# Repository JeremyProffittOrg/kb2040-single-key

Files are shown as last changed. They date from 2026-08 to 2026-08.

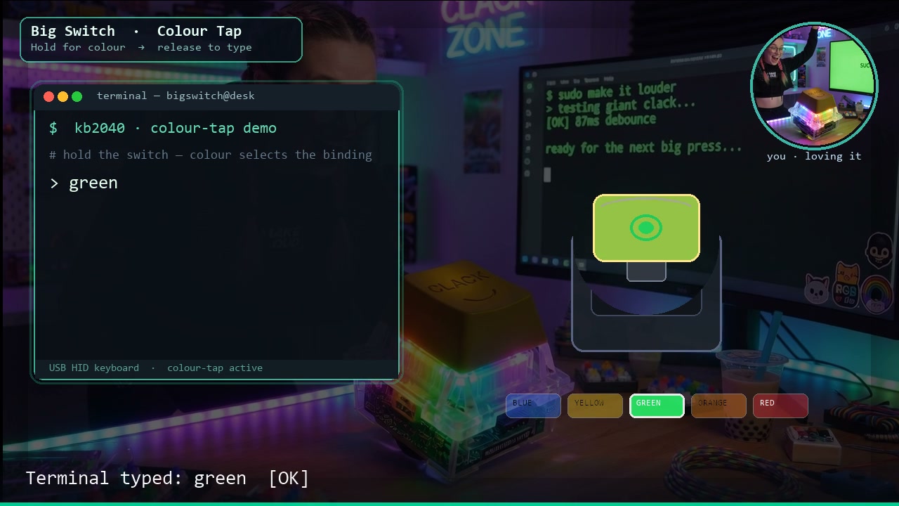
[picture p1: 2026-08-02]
docs/images/demo-hero.jpg

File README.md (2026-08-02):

# kb2040-single-key

One key. Many actions. The colour tells you which one.

https://github.com/user-attachments/assets/82b076d7-507e-4828-8a83-83113fe58dd0

An [Adafruit KB2040](https://www.adafruit.com/product/5302) with a single **Kailh Big Switch**
and a [NeoPixel Jewel](https://www.adafruit.com/product/2859) under (or beside) it, which
enumerates as a USB keyboard **and** a second USB serial port used only for configuration.
Configuration lives on the board, survives a power cycle, and is edited with a
cross-platform CLI.

Verified on an Adafruit KB2040 running **CircuitPython 10.2.1**. The default profile expects
an eight-pixel chain; with a 7-LED Jewel set `ext_count` to `7` (see
[Build guide](#build-guide)). A full command reference is in
[`docs/kb2040ctl-manual.pdf`](docs/kb2040ctl-manual.pdf).

| Core parts | Link |
|---|---|
| Controller | [Adafruit KB2040 — RP2040 Kee Boar Driver](https://www.adafruit.com/product/5302) |
| Lighting | [NeoPixel Jewel — 7 × 5050 RGB(W)](https://www.adafruit.com/product/2859) (any Jewel variant works) |
| Switch | [Kailh Big Switches](https://www.adafruit.com/category/571) (clicky blue / tactile orange / linear yellow) |
| Case | [`BigSwitchCase.stl`](BigSwitchCase.stl) · [`BigSwitchCase.scad`](BigSwitchCase.scad) |

---

## Bill of materials

### Required electronics

| Qty | Part | Adafruit / source | Notes |
|---:|---|---|---|
| 1 | **Adafruit KB2040** | [product 5302](https://www.adafruit.com/product/5302) · ~$8.95 | RP2040, Pro Micro footprint, USB-C, onboard NeoPixel |
| 1 | **NeoPixel Jewel** (7 LEDs) | [product 2859](https://www.adafruit.com/product/2859) RGBW Natural White, or [2226](https://www.adafruit.com/product/2226) RGB | ~23 mm diameter. Firmware talks plain WS2812 data on `D10` |
| 1 | **Kailh Big Switch** + keycap | [Big Switches category](https://www.adafruit.com/category/571) · ~$19.95 | [5307](https://www.adafruit.com/product/5307) clicky pale blue · [5306](https://www.adafruit.com/product/5306) tactile burnt orange · [5305](https://www.adafruit.com/product/5305) linear dark yellow |
| 1 | USB-C cable | any data-capable cable | Power + HID + config serial |

### Printed / mechanical

| Qty | Part | File | Notes |
|---:|---|---|---|
| 1 | **Big Switch case (base)** | [`BigSwitchCase.stl`](BigSwitchCase.stl) | Outer envelope ≈ **84 × 84 × 65 mm**. Print with the flat base on the bed |
| — | OpenSCAD source | [`BigSwitchCase.scad`](BigSwitchCase.scad) | Mesh polyhedron of the same solid (for inspection / remix) |

Optional: a thin diffuser disk or clear plate under the keycap if you want the Jewel to glow through the switch housing; the stock Kailh Big keycap is opaque, so many builds mount the Jewel in the base looking upward around the switch, or light the desk from under a translucent base.

### Consumables / tools

| Item | Why |
|---|---|
| Hookup wire (or short pre-crimped jumpers) | Switch to `D4`/`GND`; Jewel `DIN`/`5V`/`GND` to `D10`/`RAW`/`GND` |
| Soldering iron + solder | Headers (if used), switch legs, Jewel pads |
| Flux / flush cutters | Clean joints |
| Small flat screwdriver | **Required to release the Big Switch from the case** — see diagram below |
| 3D printer + filament | PLA or PETG for the case |

Rough electronics total (one of each, USD list prices): **≈ $35–40** before shipping, cable, and filament.

---

## Case: tab-release openings

The Big Switch snaps into the printed base. It is **not** meant to be pried out by the keycap.
On opposite sides of the case there are **square openings**. Through each opening you can reach
a plastic **retention tab** on the switch body.

1. Insert a **small flat screwdriver** into the square opening on one side.
2. Push **inward** on the tab (toward the centre of the switch).
3. Repeat on the **opposite** opening.
4. Lift the switch **straight up** out of the base.

BigSwitchCase tab-release openings — top and side views

> Do not force the housing. If a tab is still caught, go back to that side and push again
> while lifting gently. Forcing the keycap can crack the stem or the printed wall.

---

## Build guide

### 1. Print the case

- Slice [`BigSwitchCase.stl`](BigSwitchCase.stl) (or render [`BigSwitchCase.scad`](BigSwitchCase.scad)).
- Orientation: **flat base on the bed**, openings vertical.
- Suggested start: 0.2 mm layers, 15–20% infill, 3 walls. Supports usually unnecessary if
  printed base-down; enable them only if your slicer flags the openings.
- After printing, clean the two **square side openings** with a knife or small file so a
  screwdriver blade enters cleanly.

### 2. Fit-check the switch (no solder yet)

1. Align the Kailh Big Switch with the cavity (legs/orientation as your wiring prefers —
   note which side the two electrical pins face).
2. Press the switch straight down until both tabs click.
3. Practice the **tab release** with the screwdriver through both square openings so you are
   comfortable removing it before anything is wired.

### 3. Wire the electronics

Follow the [Wiring](#wiring) table. Short summary for this build:

| Connection | From | To |
|---|---|---|
| Switch contact A | Big Switch pin 1 | KB2040 **`D4`** |
| Switch contact B | Big Switch pin 2 | KB2040 **`GND`** |
| LED data | Jewel **`DIN`** (or `In`) | KB2040 **`D10`** |
| LED power | Jewel **`+` / 5V** | KB2040 **`RAW`** (USB 5 V) |
| LED ground | Jewel **`–` / GND** | KB2040 **`GND`** |

```
   KB2040                         NeoPixel Jewel (7)
   ------                         ------------------
   D10  ------------------------>  DIN
   RAW  ------------------------>  +5V
   GND  ------------------------>  GND

   D4   ---[ Kailh Big Switch ]--- GND
```

**Tips**

- Solder the Jewel first if it will sit under the switch — access is harder later.
- Keep the data wire short. If colours glitch, see the [power / 3.3 V data notes](#wiring).
- The onboard NeoPixel needs no wiring; it mirrors status on its own.
- Leave USB-C and the BOOT/RESET buttons accessible (side cutout or open base).

### 4. Install into the case

1. Seat the Jewel (and any diffuser) in the base.
2. Route wires so they do not block a tab or the square openings.
3. Snap the Big Switch in until both tabs catch.
4. Mount or tape the KB2040 in the base (or in a side pocket if you remix the case). USB-C
   should face an opening so the cable does not stress the board.

### 5. Flash firmware and set LED count

1. Install CircuitPython and flash this firmware — [Getting started](#getting-started).
2. For a **7-LED Jewel**, set the external chain length (per active profile):

```bash
kb2040ctl set profiles.0.ext_count 7
kb2040ctl set profiles.1.ext_count 7   # if you use profile 1 as well
```

3. Unplug/replug. On boot you should see the **rainbow sweep** on the onboard pixel and all
   seven Jewel LEDs. Then try a tap and a colour-hold ([The colour tap](#the-colour-tap)).

### 6. Removing the switch later

Use the square openings and a small screwdriver as in
[Case: tab-release openings](#case-tab-release-openings). Pull the switch only after **both**
tabs are free.

---

## The colour tap

A single key can only do one thing — unless you use time and colour as the extra input.

- **Tap** it (press and release quickly) and it fires the profile's **tap** binding.
- **Tap and hold** and, once past the tap window, the LEDs start cycling through colours,
  one per second. Each colour is a **slot**. Let go while a colour is showing and *that*
  slot fires.

The LED is the entire user interface: hold, watch for the colour you want, release.

```
press                                                                 
  |<-- tap window -->|<-- slot 0 --->|<-- slot 1 --->|<-- slot 2 --->|
  |     250 ms       |    1000 ms    |    1000 ms    |    1000 ms    |
  |     (white)      |     (red)     |   (orange)    |   (yellow)    |
  0                 250            1250            2250            3250 ms

  release here...    ...or here      ...or here      ...or here
  -> tap binding     -> slot 0       -> slot 1       -> slot 2
```

`tap_max_ms` (default 250) and `dwell_ms` (default 1000) are per-profile settings.

### Past the last colour

What happens when you keep holding is the per-profile `overflow` setting:

| `overflow` | behaviour |
|---|---|
| `wrap` | back to the first colour, cycling forever. Overshoot is recoverable — keep holding. |
| `wrap_cancel` | as `wrap`, but with one **dark** slot per rotation. Release while the LEDs are off and **nothing fires**. This is the escape hatch. |
| `clamp` | stay on the last colour indefinitely. Forgiving of long holds, but you can never reach an earlier slot without releasing and starting again. |

### What a binding can do

Every binding — the tap and each colour slot — is a **sequence** of steps, run in order:

| step | example | effect |
|---|---|---|
| key | `{ "key": "M", "mods": ["CTRL", "SHIFT"] }` | press with modifiers, then release |
| text | `{ "text": "On my way." }` | type the string |
| media | `{ "consumer": "PLAY_PAUSE" }` | a Consumer Control usage (play/pause, volume, …) |
| delay | `{ "delay_ms": 200 }` | wait before the next step |

So one slot can select-all-and-copy, another can type a canned reply and press Enter, and
another can mute your microphone.

### Profiles

The board stores several complete configurations and one is active at a time. Switch with
`kb2040ctl profile use 1`. Profiles are uploaded and downloaded as JSON, so you can keep as
many on disk as you like.

## Out of the box

The factory configuration has two profiles. Profile 0, `colors`, is active and is
deliberately self-describing:

| Gesture | Colour | Action |
|---|---|---|
| tap | white | **Print Screen** |
| hold → release on slot 0 | red | types `Red` |
| hold → release on slot 1 | orange | types `Orange` |
| hold → release on slot 2 | yellow | types `Yellow` |
| hold → release on slot 3 | green | types `Green` |
| hold → release on slot 4 | cyan | types `Cyan` |
| hold → release on slot 5 | blue | types `Blue` |
| hold → release on slot 6 | violet | types `Violet` |
| hold → release on slot 7 | magenta | types `Magenta` |

One slot per LED in the default eight-pixel chain, in the same order the startup rainbow
sweeps them. Because each slot types the name of the colour it is showing, the gesture
teaches itself: hold, watch the strip, release, and the word that appears tells you whether
you let go when you meant to.

Profile 1, `media`, is play/pause on tap with mute, volume and track controls on the colour
slots — switch to it with `kb2040ctl profile use 1`.

---

## Wiring

Reference hardware for this repo is the **KB2040 + Kailh Big Switch + NeoPixel Jewel**
build described in the [Bill of materials](#bill-of-materials) and
[Build guide](#build-guide). Any momentary switch to ground and any WS2812-compatible chain
on `D10` will work the same electrically.

| Function | Pin | Notes |
|---|---|---|
| Key switch (Kailh Big Switch) | `D4` (GP4) | other leg to `GND`. Internal pull-up, active low — no resistor needed. |
| Onboard NeoPixel | `NEOPIXEL` (GP17) | already on the board, nothing to wire |
| External WS2812 data (Jewel `DIN`) | `D10` (GP10) | first pixel's `DIN` |
| External WS2812 power | `RAW` (5 V) and `GND` | see the power note below |

```
   KB2040                      WS2812 chain / NeoPixel Jewel
   ------                      -----------------------------
   D10  --------------------->  DIN
   RAW  --------------------->  5V
   GND  --------------------->  GND
                                 |
   D4   ---[ key switch ]--- GND |
```

**Power.** A WS2812 draws up to ~60 mA at full white. `RAW` comes straight from USB VBUS, so
the practical ceiling is what the host port will give — budget roughly 8–10 pixels before
adding a separate 5 V supply (tie its ground to the board's). A 7-LED Jewel is well inside
that. The default `brightness` of 64 keeps a chain of 7–8 to about a fifth of full-white draw.

**3.3 V data into a 5 V part.** The RP2040's output is 3.3 V and WS2812 datasheets ask for
0.7 × VDD. It usually works at short distances, and reliably if you power the chain at
4.5 V or use WS2812B-family parts. If the first pixel flickers or shows wrong colours, that
is the reason — add a level shifter or drop the strip supply.

To use different pins, change `KEY_PIN` and `EXT_PIN` at the top of `src/code.py`.

---

## Getting started

### 1. Put CircuitPython on the board

Skip this if the board already shows up as a `CIRCUITPY` drive.

Get it into the UF2 bootloader so an `RPI-RP2` drive appears:

- **double-tap RESET** quickly, or
- **hold BOOT while tapping RESET** (or while plugging the USB cable in), or
- if the board is running an **Arduino** sketch, the double-tap often does nothing — use the
  standard Arduino *1200-baud touch* instead: open its serial port at 1200 baud and close
  it, and it reboots into the bootloader.

Then copy the [KB2040 CircuitPython build](https://circuitpython.org/board/adafruit_kb2040/)
onto `RPI-RP2`. The board reboots as `CIRCUITPY`.

> **Get the board-specific build.** Nothing on the bootloader drive identifies the board —
> `INFO_UF2.TXT` always reads `Model: Raspberry Pi RP2`, because the bootloader lives in the
> RP2040's mask ROM and is identical on every RP2040. The `.uf2` is what defines
> `board.NEOPIXEL`, `board.D4` and `board.D10`, so the wrong one breaks exactly the pins this
> firmware uses. Once CircuitPython is on, `boot_out.txt` names the board for real.

### 2. Flash the firmware

```powershell
pip install -r requirements-dev.txt
pwsh scripts/flash.ps1          # Windows
```

```bash
pip install -r requirements-dev.txt
scripts/flash.sh                # macOS and Linux
```

Both install the CircuitPython libraries with `circup` and copy `src/` onto the drive. If the
volume is mounted somewhere unusual — common on headless Linux, which may not automount at
all — pass it explicitly: `scripts/flash.sh --drive /mnt/CIRCUITPY`.
Then **unplug and replug the board** — `boot.py` only takes effect on a hard reset, and it
is what creates the second serial port.

On every start the board runs a **rainbow sweep** across the onboard NeoPixel and the whole
external chain, then settles into the profile's idle animation. That is the self-test: if
all your pixels light and show a smooth spread of colour, the data line, the chain length
and the power are all good. It runs regardless of the profile's `idle_mode` and stays
visible even at `brightness: 0`, because it is the only diagnostic the board has before
anything can talk to it.

### 3. Build the CLI

```bash
go build -o kb2040ctl ./cli/cmd/kb2040ctl
```

Or download a prebuilt binary from the releases page — Windows, macOS and Linux, amd64 and
arm64, no runtime to install.

Two per-platform notes, both covered in the [manual](docs/kb2040ctl-manual.pdf): macOS
quarantines a downloaded binary, so clear it with
`xattr -d com.apple.quarantine ./kb2040ctl`; and on Linux `/dev/ttyACM*` belongs to the
`dialout` group, so `sudo usermod -aG dialout "$USER"` (then log out and in) avoids
*permission denied*.

### 4. Check it

```console
$ kb2040ctl ports
   COM27        USB Serial Device (COM27)  [USB 239A:8106]
-> COM28        USB Serial Device (COM28)  [USB 239A:8106]
   COM3         Standard Serial over Bluetooth link (COM3)

$ kb2040ctl info
port       COM28
firmware   0.1.0 (format 1)
storage    204 / 4096 bytes used (3892 free)

* 0  colors           8 slots, 1000ms dwell, wrap overflow, 8 LEDs
  1  media            6 slots, 1000ms dwell, wrap_cancel overflow, 8 LEDs
```

Two ports appear because the board exposes both the REPL console and the config port
(`COM27`/`COM28` on Windows, `/dev/ttyACM0`/`/dev/ttyACM1` on Linux, `/dev/cu.usbmodem*` on
macOS). They have identical USB IDs, so `kb2040ctl` finds the right one by asking each until
one answers. Bluetooth ports are never probed — opening an idle one on Windows can block for
minutes — and on macOS only the `/dev/cu.*` names are tried, since opening a `/dev/tty.*`
twin waits forever for carrier detect.

---

## Configuring

### Edit one thing

```bash
kb2040ctl set profiles.0.dwell_ms 1500
kb2040ctl set profiles.0.slots.2.color "#00FF80"
kb2040ctl set profiles.0.slots.0.steps.0.text "Back in five."
kb2040ctl get profiles.0.overflow
```

`set` downloads the configuration, applies the edit, validates it and uploads the result —
the board is only ever written whole, so a half-applied configuration is not possible.

### Edit a file

```bash
kb2040ctl download -o mine.json     # whole device
$EDITOR mine.json
kb2040ctl validate mine.json        # check it without a board attached
kb2040ctl upload mine.json
```

Or one profile at a time:

```bash
kb2040ctl download -p 0 -o media.json
kb2040ctl upload -p 1 examples/meetings.json
```

### Tune the timing by feel

```console
$ kb2040ctl watch
Watching. Tap and hold the key; press Ctrl-C to stop.
press
slot 0 FF0000
slot 1 FF6000
slot 2 FFC000
release
fire 3
```

If you keep overshooting, raise `dwell_ms`. If a deliberate tap keeps landing on slot 0,
raise `tap_max_ms`.

---

## Command reference

| Command | What it does |
|---|---|
| `kb2040ctl ports` | list serial ports and show which one is the board |
| `kb2040ctl info` | show firmware version, storage use and the active profile |
| `kb2040ctl download [-p N] [-o FILE]` | save the device's configuration as JSON |
| `kb2040ctl upload [-p N] FILE` | send a JSON configuration to the device |
| `kb2040ctl get PATH` | print one value from the device's configuration |
| `kb2040ctl set PATH VALUE` | change one value and upload the result |
| `kb2040ctl profile list\|use N` | list profiles or switch the active one |
| `kb2040ctl test PROFILE BINDING` | fire a binding now (binding 0 is the tap) |
| `kb2040ctl watch` | print key and colour-slot events live |
| `kb2040ctl validate FILE` | check a configuration file without a device |
| `kb2040ctl defaults` | restore the factory configuration |
| `kb2040ctl keys [media]` | list the key and media names a config can use |
| `kb2040ctl version` | print this tool's version |

Every command that talks to the board takes `-port COM7` (or `/dev/ttyACM1`) to skip
autodetection. `validate`, `keys` and `version` need no board at all.

---

## Configuration format

```jsonc
{
  "format": 1,
  "active": 0,
  "profiles": [
    {
      "name": "media",          // up to 16 bytes
      "dwell_ms": 1000,         // 100..10000 - how long each colour shows
      "tap_max_ms": 250,        // 20..2000  - release under this is a tap
      "overflow": "wrap",       // wrap | wrap_cancel | clamp
      "ext_count": 8,           // 0..64 external WS2812s, 0 disables the chain
      "brightness": 64,         // 0..255
      "idle_mode": "breathe",   // off | solid | breathe | rainbow
      "idle_color": "#001018",
      "tap":   { "color": "#FFFFFF", "steps": [ { "consumer": "PLAY_PAUSE" } ] },
      "slots": [                // 1..16 colour slots, in cycle order
        { "color": "#FF0000", "steps": [ { "consumer": "MUTE" } ] },
        { "color": "#00FF00", "steps": [ { "text": "brb" },
                                         { "delay_ms": 200 },
                                         { "key": "ENTER" } ] }
      ]
    }
  ]
}
```

A step sets exactly one of `key`, `text`, `consumer` or `delay_ms`. `mods` only accompanies
`key`, and accepts `CTRL`, `SHIFT`, `ALT`, `GUI` (also `WIN`/`CMD`), and the `R`-prefixed
right-hand forms.

Run `kb2040ctl keys` for every key name and `kb2040ctl keys media` for the media names.

Working examples are in [`examples/`](examples/): `default.json` (the factory
configuration), `dev-hotkeys.json` and `meetings.json`.

### The byte budget

Everything lives in the RP2040's 4096-byte non-volatile region, which is what lets the
configuration persist while the `CIRCUITPY` drive stays writable from your PC. There is no
fixed per-profile limit — spend the space how you like:

```console
$ kb2040ctl validate mine.json
mine.json is valid: 3 profile(s), 620 / 4096 bytes (3476 free)
  0  colors           8 slots, 115 bytes
  1  media            6 slots, 73 bytes
  2  meetings         4 slots, 169 bytes
```

An upload that would not fit is refused before anything is sent, and refused again by the
board. Roughly: a slot with a short key or media action costs about 8 bytes, and a slot with
a typed sentence costs about 6 bytes plus the length of the text.

---

## Troubleshooting

**Only one serial port appears.** `boot.py` has not run. It only takes effect on a *hard*
reset — unplug and replug, or press the reset button. A soft reload is not enough.

**`no kb2040-single-key found on any of: ...`** Either the board is not running this
firmware, or something else already has the port open (a serial monitor, the Mu editor).
Close it and try again, or pass `-port` explicitly.

**`kb2040ctl info` reports a `status` that is not `ok`.** The board could not read its
stored configuration and fell back to the factory defaults; the status says why (`blank` on
a board that has never been configured, `corrupt: ...` otherwise). Uploading a configuration
clears it.

**No `CIRCUITPY` drive at all.** The board is not running CircuitPython — it may still have
whatever firmware came on it. Go back to step 1. A board running an Arduino sketch enumerates
as a single serial port with no drive, and its USB vendor ID is `2E8A` (Raspberry Pi) rather
than Adafruit's `239A`.

**No startup rainbow at all.** The firmware is not running. Check the REPL on the *console*
serial port for a traceback — a missing library (`adafruit_hid`, `neopixel`) is the usual
cause, so re-run `scripts/flash.ps1` without `-SkipLibraries`.

**Startup rainbow on the onboard pixel but not the chain.** Either `ext_count` is 0
(`kb2040ctl get profiles.0.ext_count`) or the chain is not receiving data — check `D10` to
the *first* pixel's `DIN`, and that the strip's ground is tied to the board's.

**Only some of the chain lights during the startup rainbow.** `ext_count` is smaller than
the number of pixels you attached. `kb2040ctl set profiles.0.ext_count 8`.

**The key does nothing but the LEDs work.** The switch is not reaching `D4`/`GND`. Check with
`kb2040ctl watch` — no `press` line means the firmware never sees the key.

**The LEDs work but the key types the wrong thing.** Fire the binding directly with
`kb2040ctl test 0 3` to separate a wiring/timing problem from a configuration problem.

---

## Development

```bash
python -m pytest tests -q     # firmware logic - no hardware needed
go test ./cli/...             # CLI and wire format
go vet ./cli/...
```

The manual is built from [`docs/manual.md`](docs/manual.md):

```bash
python scripts/build-manual.py    # -> docs/kb2040ctl-manual.pdf
```

Everything under `src/singlekey/` deliberately imports nothing from CircuitPython, so the
gesture state machine, LED engine, binary codec, Ascii85 codec and serial protocol all run
under host pytest. Only `src/boot.py` and `src/code.py` touch hardware, and a test enforces
that boundary.

The binary format and serial protocol are specified in [`docs/format.md`](docs/format.md),
which is authoritative for both implementations. They are pinned together by golden vectors
in `tests/fixtures/`, generated by the Go encoder and asserted byte-for-byte by the Python
tests — change one side without the other and CI fails.

After an intentional format change:

```bash
go test ./cli/... -update     # regenerate tests/fixtures and examples/default.json
python -m pytest tests -q     # confirm the firmware agrees
```

Planning and progress notes live in [`plan.md`](plan.md).

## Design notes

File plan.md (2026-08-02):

# plan.md — kb2040-single-key: color-tap firmware + Go CLI

## Context

`C:\dev\kb2040-single-key` contains only the org bootstrap files (`CLAUDE.md`, `agents.md`,
`deploy.md`, `scripts/set-secret.*`). No firmware, no source, no tests, no CI. Greenfield.

Target: an Adafruit **KB2040 (RP2040)** with **one physical key** that enumerates over USB
as a composite device — an HID keyboard/consumer-control device plus a **second CDC serial
port** used only for configuration — and drives **WS2812 RGB LEDs** (onboard `board.NEOPIXEL`
GP17 + an external chain).

The interaction model is the **color tap**:

- **Tap** (press and release quickly) fires the profile's *tap* binding.
- **Tap and hold**: past the tap window the LED begins cycling colors, one color per second.
  Each color is a **slot**. Releasing while a color is showing fires *that slot's* binding.
  The LED colour is the whole UI — you hold, watch for the colour you want, release.

Every binding (the tap and each colour slot) runs a **multi-step sequence**: any ordered mix
of key+modifier presses, typed text (automated responses), media keys, and delays.

The device stores **multiple profiles**; profiles and whole-device configs **upload and
download** over the serial port, driven by a **Go CLI cross-compiled for Windows, Linux and
macOS**.

## Locked decisions (user-confirmed 2026-08-01; do not revisit)

1. **Firmware stack: CircuitPython.** `usb_hid`, `usb_cdc.data`, `neopixel`. Not KMK, Rust,
   or Arduino.
2. **Persistence: `microcontroller.nvm`.** No `storage.remount()`, no `config.json` on the
   filesystem — the CIRCUITPY drive stays writable from the PC.
3. **LEDs: onboard + external chain.** `board.NEOPIXEL` (GP17) and an external WS2812 chain
   on `board.D10` (GP10), chain length set in config.
4. **Bindings support multi-step sequences** — key+mods, typed text, media/Consumer Control,
   and delays, in any order, per binding.
5. **Multiple profiles stored on the device**, with an active-profile selector, plus
   upload/download of profiles and whole-device configs.
6. **Overflow behaviour past the last colour slot is configurable per profile**:
   `wrap` (cycle back to the first colour), `wrap_cancel` (one dark slot per rotation where
   releasing fires nothing), or `clamp` (stay on the last colour indefinitely).
7. **Go CLI lives in this repo under `cli/`; CI cross-compiles and publishes binaries**
   (windows/linux/darwin × amd64/arm64) as release artifacts.
8. **Ascii85 is the serial wire encoding** for blob upload/download — not base64.

## Verified facts

- `git ls-files`: `CLAUDE.md`, `agents.md`, `deploy.md`, `scripts/set-secret.cmd`,
  `scripts/set-secret.sh`. Branch `main`, clean, one commit `4268f13`.
- `CLAUDE.md`: commit and push directly to `main`; every push is a production deploy; no
  stubs or placeholders; no `Co-Authored-By` trailer.
- `deploy.md`: AWS deploys are GitHub Actions + OIDC, never local. See "Deviation" below —
  this repo ships firmware and a CLI, not AWS infrastructure.

## Assumptions (verified during implementation, not before)

- Board is a genuine KB2040 running CircuitPython 9.x, mounting as `CIRCUITPY`. The exact
  version is read from `boot_out.txt` at bring-up.
- **`microcontroller.nvm` is ~4096 bytes.** The whole storage design hangs on this; it is
  checked first (WS-B1) and a shortfall is a stop condition.
- Switch is a plain momentary contact to GND, internal pull-up, active low. No matrix.

## The storage tension (stated, then solved)

Multiple profiles × up to 9 bindings each × multi-step sequences containing text does not
fit in ~4KB as JSON. Two consequences, both designed in rather than discovered later:

- **The on-device format is compact little-endian binary, not JSON.** Estimated cost: a
  binding with a 64-char text step ≈ 70 bytes; a 9-binding profile with a few such steps
  ≈ 700–900 bytes; ~4 profiles fit in 4080 usable bytes.
- **There is no fixed per-profile cap.** The blob is fully variable-length with a profile
  offset table, so you can keep 2 large profiles or 6 small ones. The **Go CLI reports byte
  usage** (`2143 / 4080 bytes`) and refuses an upload that would overflow; the device
  independently rejects an oversized write. Nothing silently truncates.

## On-device binary format (`docs/format.md` is the single source of truth)

```
Blob      magic "KB2K" (4) | fmt_ver u8 =1 | flags u8 | active u8 | nprofiles u8
          | offsets u16[nprofiles]  (LE, from blob start)
          | profile records ...
          | crc16 u16 (CCITT, over all preceding bytes)

Profile   name_len u8 | name UTF-8 (<=16) | dwell_ms u16 | tap_max_ms u16
          | overflow u8 (0 wrap, 1 wrap_cancel, 2 clamp)
          | ext_count u8 | brightness u8
          | idle_mode u8 (0 off, 1 solid, 2 breathe, 3 rainbow) | idle_color u8[3]
          | nslots u8 | binding[0] (tap) | binding[1..nslots]

Binding   color u8[3] | nsteps u8 | step ...

Step      type u8, then:
          0 key       keycode u8, mods u8
          1 text      len u8, bytes
          2 consumer  code u16
          3 delay     ms u16
```

Defaults: `dwell_ms` 1000, `tap_max_ms` 250, `nslots` 8, `overflow` wrap.

**Timing model.** Press → LED shows the tap binding's colour. Release before `tap_max_ms`
fires the tap binding. Otherwise slot *i* occupies
`[tap_max_ms + i*dwell_ms, tap_max_ms + (i+1)*dwell_ms)`; releasing during slot *i* fires
binding *i+1*. Past the last slot, `overflow` decides.

## Division of labour (deliberate)

**All JSON ↔ binary translation lives in the Go CLI.** The device transfers the raw blob as
**Ascii85** and never parses JSON. This keeps CircuitPython small and the config schema
evolvable in one place.

**Wire encoding: Ascii85** (btoa flavour — no `<~ ~>` wrapper, `z` shortcut for all-zero
groups). 25% overhead vs base64's 33%: a full 4080-byte blob is ~5.1KB on the wire instead
of ~5.5KB, and the charset (ASCII 33–117) is entirely safe for a newline-delimited line
protocol. Go gets this from stdlib `encoding/ascii85`, whose decoder also ignores the
newlines introduced by chunking. **CircuitPython's `binascii` has no Ascii85**, so
`src/singlekey/a85.py` is a hand-written codec (encode + decode, `z` shortcut, strict
rejection of out-of-range characters and malformed final groups) — pure, host-testable, and
pinned to Go's implementation by its own golden vector.

Consequence: the device needs a binary **decoder** (to run the config) and a minimal
**encoder** (only to write factory defaults into blank NVM). The two implementations are
pinned together by a **cross-language golden vector**: Go encodes the canonical default
config to `tests/fixtures/default.bin` (committed); a Python test asserts its encoder
produces byte-identical output, and a Go test asserts its decoder round-trips it. If the
two ever drift, CI fails.

There is no device-side `set <field>` command. The CLI's `set` is download → modify → upload,
so the blob is always written atomically and there is one source of truth for the schema.

## Serial protocol (line-based, `\n`, on `usb_cdc.data`)

`version` → firmware version, format version, NVM size, bytes used ·
`read` → Ascii85 blob in chunked lines (80 chars/line), terminated by `OK` ·
`write <len> <crc16>` then Ascii85 chunks → device verifies length + CRC before committing,
rejects on mismatch without touching the live config ·
`profile <n>` → set active profile (fast path, no full rewrite) ·
`test <profile> <binding>` → fire a binding on demand ·
`events on|off` → stream `EV press` / `EV slot <i> <RRGGBB>` / `EV fire <binding>` /
`EV release` for the CLI's `watch` ·
`defaults` → rewrite factory defaults · `help`.

Every command ends in exactly one `OK`/`OK <detail>` or `ERR <reason>` line.

## Hardware contract (README table; constants in `code.py`)

| Function | Pin | Notes |
|---|---|---|
| Key switch | `board.D4` (GP4) | other leg to `GND`, internal pull-up, active low |
| Onboard NeoPixel | `board.NEOPIXEL` (GP17) | 1 pixel, mirrors the slot colour |
| External WS2812 data | `board.D10` (GP10) | length = `ext_count` |
| External power | `RAW`/5V + `GND` | current budget + 3.3V-data caveat in README |

## Layout

```
src/boot.py                    usb_cdc.enable(console+data); usb_hid.enable([KBD, CC])
src/code.py                    wiring + non-blocking main loop
src/singlekey/blob.py          binary decoder + minimal defaults encoder + crc16
src/singlekey/nvmstore.py      microcontroller.nvm read/write, corruption recovery
src/singlekey/colortap.py      press/hold/slot/overflow state machine  (pure)
src/singlekey/leds.py          idle animations + slot colour + fire flash (pure)
src/singlekey/actions.py       step interpreter over adafruit_hid
src/singlekey/a85.py           Ascii85 codec (CircuitPython has none)       (pure)
src/singlekey/protocol.py      command dispatch, Ascii85 chunked transfer   (pure)
cli/                           Go module: cmd/kb2040ctl + internal/{blob,serial,config}
docs/format.md                 binary format spec (authoritative)
tests/                         pytest + CircuitPython stubs + golden fixture
examples/*.json                sample profiles
```

`src/lib/` (circup-installed `adafruit_hid`, `neopixel`, `adafruit_pixelbuf`) is gitignored,
not vendored. `colortap`, `leds`, `blob`, `a85`, and `protocol` take no CircuitPython
imports at module scope so they run under host pytest.

## Workstreams

**WS-A gates everything** (it defines the wire format). WS-B and WS-C then run in parallel;
WS-D and WS-E can start any time after A.

### WS-A — format contract

- [x] A1 `docs/format.md` — the spec above, authoritative for both implementations.
- [x] A2 Go `internal/blob` — encoder, decoder, crc16, byte-budget accounting, JSON schema
      for the host-facing config, validation with actionable error messages.
- [x] A3 Canonical default config JSON + generated `tests/fixtures/default.bin` and
      `tests/fixtures/default.a85` (stdlib `encoding/ascii85` output of that blob).

**DoD:** `go test ./cli/...` passes, including a fuzz-lite round-trip test
(JSON → binary → JSON is identity) and a byte-budget overflow test.

### WS-B — device firmware

- [!] B1 **BLOCKED (no board attached)**: verify `microcontroller.nvm` exists and its size
      on the real board. Unblocked by plugging in a KB2040 running CircuitPython.
      (REPL, one line). A shortfall is stop condition 1.
- [x] B2 `blob.py` decoder + defaults encoder + `nvmstore.py`; blank/corrupt NVM falls back
      to factory defaults and reports why — never bricks the boot.
- [x] B3 `colortap.py` — tap/hold/slot/overflow state machine, tick-driven, all three
      overflow modes.
- [!] B4 **BLOCKED (no board attached)**: on-hardware bring-up — confirm two COM ports
      enumerate and `boot_out.txt` records the CircuitPython version.
- [x] B5 `actions.py` — step interpreter (key+mods, text, consumer, delay).
- [x] B5a `a85.py` — Ascii85 encode/decode with the `z` shortcut, strict on bad input;
      tested against `tests/fixtures/default.a85` and over random byte strings of every
      length mod 4 (the padding edge cases are where hand-rolled Ascii85 goes wrong).
- [x] B6 `boot.py` + `protocol.py` + `code.py` — dual CDC, HID devices, non-blocking loop,
      exception guard so a bad action never takes down the config port.

**DoD (host):** `python -m pytest tests -q` exits 0, including the two golden-vector tests —
Python's encoder matches `tests/fixtures/default.bin` byte for byte, and Python's Ascii85
matches `tests/fixtures/default.a85` (Go stdlib output) in both directions.
**DoD (hardware):** two COM ports enumerate; `kb2040ctl info` reports version and byte usage.

### WS-C — Go CLI (`kb2040ctl`)

Transport: `go.bug.st/serial` (no cgo, so cross-compilation stays trivial). Port autodetect
probes candidate ports with a `version` handshake rather than hardcoding a PID — that also
picks the *data* port over the console port.

- [x] C1 Serial transport + autodetect + `--port` override.
- [x] C2 `info`, `ports`, `profile list|use|name`, `test`, `defaults`.
- [x] C3 `download [-p N] -o file.json`, `upload file.json [-p N]` — whole-device or single
      profile, with byte-usage reporting and pre-flight overflow refusal.
- [x] C4 `set <path> <value>` implemented as download → modify → upload.
- [x] C5 `validate file.json` — fully offline, no device, prints byte budget.
- [x] C6 `watch` — live `EV` stream, so dwell timing can be tuned by feel.

**DoD:** `go vet ./cli/...` and `go test ./cli/...` pass; `kb2040ctl validate
examples/default.json` exits 0 with a byte report; `GOOS/GOARCH` build succeeds for all six
targets.

### WS-D — CI and release

- [x] D1 `.github/workflows/ci.yml` — on push to `main` and PRs: `pytest`, `go vet`,
      `go test`, and the cross-language golden-vector check. **No AWS credentials, no OIDC
      job, no `id-token` permission.**
- [x] D2 `.github/workflows/release.yml` — on `v*` tags: cross-compile six targets, attach
      to a GitHub release (`contents: write`, `GITHUB_TOKEN` only — no secrets to add).

**DoD:** `gh run watch <id>` reaches `completed / success` on the push to `main`.

### WS-E — tooling and docs

- [x] E1 `scripts/flash.ps1` — find the `CIRCUITPY` volume, `circup install` deps, mirror
      `src/`; refuse to run if no CIRCUITPY volume is present.
- [x] E2 `README.md` — wiring, the colour-tap model with a timing diagram, the full command
      reference, config JSON schema with examples, byte-budget guidance, install/flash steps.
- [x] E3 `examples/` — a few real profiles (media control, canned text responses, hotkeys).

**DoD:** `README.md`'s command reference matches the CLI's registered commands, asserted by
a Go test rather than by eye.

## Deviation from deploy.md (flagged, not silently taken)

`deploy.md` assumes every repo deploys AWS infrastructure via GitHub Actions + OIDC. This
repo produces firmware copied to a USB drive plus a CLI binary — there is no stack, no
`samconfig.toml`, and no OIDC deploy job to write. CI runs tests; the tag workflow publishes
binaries with `GITHUB_TOKEN`. `scripts/flash.ps1` writing to a locally attached CIRCUITPY
volume is not a "local deploy" in deploy.md's sense (that rule targets `aws`/`sam`/`cdk`
against production), but it is the one place local action touches the device, so it is
called out rather than assumed. Credential rules hold in full: nothing here reads, prints,
or commits a secret, and no secret is required.

## Stop conditions (only these)

1. `microcontroller.nvm` is unavailable or materially smaller than ~4KB — multi-profile
   storage is a locked decision and the filesystem fallback was explicitly rejected, so the
   trade-off (fewer profiles, shorter strings, or revisiting storage) is an operator call.
2. No CIRCUITPY volume / board does not enumerate — WS-A, WS-C, WS-D, WS-E still complete
   in full; WS-B parks as `[!]` with the hardware steps listed.
3. Any request to add AWS resources, secrets, or a deploy job beyond test + release CI.

Everything else — library versions, pin reassignment, protocol wording, command naming — is
worked around and recorded in the execution log.

## Verification (end to end)

1. `python -m pytest tests -q` and `go test ./cli/...` — green, including both
   cross-language golden vectors (binary blob and Ascii85).
2. `pwsh scripts/flash.ps1`; replug; confirm **two** COM ports.
3. `kb2040ctl info` — firmware version, format version, `N / 4080 bytes used`.
4. `kb2040ctl download -o mine.json`; edit; `kb2040ctl upload mine.json`; `download` again
   and diff — round-trip is identity.
5. **Tap** the key → tap binding fires (e.g. types the canned response).
6. **Hold** → LED changes colour once per second; release on the 3rd colour → slot 3's
   sequence fires. Repeat for slot 1 and the last slot.
7. Set `overflow` to each of `wrap`, `wrap_cancel`, `clamp`; hold past the last slot and
   confirm each behaviour, including that `wrap_cancel`'s dark slot fires nothing.
8. `kb2040ctl profile use 2` → confirm a different profile's colours and actions.
9. **Unplug and replug** → `kb2040ctl download` shows every saved value intact (the NVM
   persistence proof) and the active profile is remembered.
10. `kb2040ctl upload` an oversized config → refused with a byte-budget error, device
    unchanged (`download` still returns the previous config).
11. Push to `main`, `gh run watch <id>` green; tag `v0.1.0` and confirm six binaries attach.

## First implementation step

Mirror this file to `C:\dev\kb2040-single-key\plan.md` (repo-root plan is the source of
truth for committed work), with an `## Execution log` appended as work lands.

## Execution log

Appended in place as work lands: commands run, commits, identifiers, and what each
verification actually returned.

### 2026-08-01 — WS-A complete (format contract)

- `docs/format.md` written as the authoritative spec (format version 1, CRC-16/CCITT-FALSE,
  little-endian, variable-length profile records with a u16 offset table).
- Go module `cli/` (module path `github.com/JeremyProffittOrg/kb2040-single-key/cli`),
  packages `internal/blob` (types, validation, encode/decode, key/consumer name tables,
  host JSON) and `internal/wire` (Ascii85, 80-char lines, stdlib `encoding/ascii85`).
- `go vet ./...` clean. `go test ./... ` passes: CRC check value 0x29B1, encode/decode
  round-trip, JSON round-trip, 300 pseudo-random configs through both round-trips,
  byte-budget rejection, and 8 corruption cases (bad magic, bad version, flipped bit,
  truncation, zero profiles, out-of-range active, out-of-bounds offset).
- Golden fixtures generated with `go test ./... -update`:
  `tests/fixtures/default.bin` (181 bytes), `tests/fixtures/default.a85` (230 bytes),
  `examples/default.json`.
- **Verified byte budget: the two-profile factory default is 181 / 4096 bytes.** The storage
  tension flagged at plan time is not binding in practice — there is room for roughly 8
  profiles of this size.

### 2026-08-01 — WS-B complete (device firmware, host side)

- `src/singlekey/`: `a85`, `blob`, `nvmstore`, `colortap`, `leds`, `actions`, `protocol`,
  `ticks`. `src/boot.py` (dual CDC + HID device selection) and `src/code.py` (Device,
  KeyReader, SerialLines, main loop) are the only hardware-touching modules.
- `python -m pytest tests -q` → **137 passed**. Includes both cross-language golden vectors
  (`tests/fixtures/default.bin`, `tests/fixtures/default.a85`), a third-implementation
  cross-check against CPython's `base64.a85encode`, and a structural test asserting no
  module under `src/singlekey` imports CircuitPython.
- Format change during implementation: added `blob_len` (u16 at offset 8) so a blob is
  self-delimiting. The firmware is handed the whole 4096-byte NVM region and must find the
  end of the blob before it can verify the CRC that sits there. `docs/format.md` and the
  fixtures were regenerated together.
- Protocol change during implementation: dropped the `.` transfer terminator. Every
  candidate terminator character is itself legal Ascii85 and a final line can be a single
  character, so a terminator is genuinely ambiguous. Instead the encoder never emits the
  `z` shorthand, which makes `encoded_len(n)` exact, and the device frames an upload by
  counting characters. A 5-second silence timeout stops an abandoned upload wedging the port.
- Gotcha recorded: `src/` must be **appended** to `sys.path`, never prepended — CircuitPython
  requires the entry point to be `code.py`, which shadows the stdlib `code` module that pdb
  imports, and pytest fails to start.

### 2026-08-01 — WS-C complete (Go CLI)

- `cli/cmd/kb2040ctl` (13 commands) plus `internal/device` (serial transport, handshake
  autodetect, upload framing) and `internal/patch` (dotted-path edits).
- Dependency: `go.bug.st/serial v1.8.0`.
- `go vet ./...` clean; `go test ./...` passes. The device client is tested against
  `internal/device/fake_test.go`, an independent in-memory implementation of the protocol,
  covering upload framing, EV-line interleaving, ERR handling and command timeouts.
- Bug found and fixed by that suite: `wire.Decode` sized its output buffer at `len*4/5`,
  but a `z` shortcut expands one character to four bytes, so `z`-containing input was
  silently truncated. Now `4*len+4`.
- macOS note: `go.bug.st/serial/enumerator` needs cgo (IOKit). Rather than force a
  multi-runner release matrix, `ports_detailed.go` / `ports_basic.go` are build-tagged, so
  cgo-less darwin builds fall back to port names only. Autodetect identifies the board by
  protocol handshake either way.
- **Verified: all six targets build with `CGO_ENABLED=0`** (windows/linux/darwin ×
  amd64/arm64). `kb2040ctl validate examples/default.json` exits 0 and reports
  `183 / 4096 bytes (3913 free)`.

### 2026-08-01 — WS-D and WS-E complete (CI, docs, tooling)

- `.github/workflows/ci.yml`: three jobs on push to `main` and on PRs — `firmware`
  (pytest), `cli` (gofmt, go vet, go test, plus a check that the generated fixtures match
  what is committed), and a six-target `cross-compile` matrix with `CGO_ENABLED=0`.
  **Top-level `permissions: contents: read`; no AWS credentials, no OIDC, no `id-token`.**
- `.github/workflows/release.yml`: on a `v*` tag, runs the tests, builds all six targets
  with `-trimpath -ldflags "-s -w -X main.Version=<tag>"`, writes `SHA256SUMS`, and publishes
  with `gh release create --generate-notes`. `contents: write` + `GITHUB_TOKEN` only; no
  secret needs adding.
- `requirements-test.txt` split out of `requirements-dev.txt` so CI installs pytest alone
  and does not drag in `circup`.
- `scripts/flash.ps1`: finds the CIRCUITPY volume, refuses to run without one, verifies
  `boot_out.txt`, installs the libraries with circup, and mirrors `src/` — deleting
  `singlekey/` first so a module removed from the repo cannot linger on the board.
- `README.md`: wiring table and diagram, the colour-tap timing diagram, all three overflow
  modes, power and 3.3V-data caveats, the full command reference, the config schema, the
  byte budget, and troubleshooting.
- `examples/dev-hotkeys.json` (91 bytes) and `examples/meetings.json` (183 bytes), both
  verified with `kb2040ctl validate -p`.
- **DoD met:** `cli/cmd/kb2040ctl/readme_test.go` asserts the README's command reference and
  the CLI's registered commands match in both directions — a missing entry and an invented
  one both fail.

### 2026-08-01 — CI green, software complete

- `gh run watch 30717747591` → **completed / success**, 8/8 jobs.
- Bumped `actions/checkout@v5`, `setup-go@v6`, `setup-python@v6` to clear the Node 20
  deprecation annotations. `gh run watch 30717793069` → **completed / success**, 8/8 jobs,
  zero annotations.

**Everything that does not need the physical board is done.** Remaining work is stop
condition 2: WS-B1 and WS-B4 are `[!]`, unblocked by attaching a KB2040 running
CircuitPython. The rest of the hardware verification list is in "Verification (end to end)"
above, steps 2–9.

Note on assumptions still unproven: `microcontroller.nvm` being ~4096 bytes is asserted in
the code (`blob.NVM_SIZE`) but has not been read off a real board. If it turns out smaller,
the byte-budget reporting already surfaces it — the factory default is 183 bytes, so even a
much smaller region would work; only the number quoted as "free" would change.
### 2026-08-01 — startup rainbow added; hardware bring-up blocked on firmware, not wiring

- Added `LedEngine.boot_frame()` and `Device.startup_sweep()`: a one-shot rainbow across the
  onboard NeoPixel and the full external chain at every start, fading out into the idle
  animation. Ignores `idle_mode` and enforces a brightness floor, because it is the only
  diagnostic the board has before the config port exists. 11 new tests; suite now **148**.
  CI run 30719755561 green.
- **Hardware finding (blocks B1/B4):** the attached board enumerates as
  `USB\VID_2E8A&PID_8105`, `BusReportedDesc: PicoArduino`, one CDC port (COM25), and **no
  CIRCUITPY or RPI-RP2 volume**. VID `2E8A` is Raspberry Pi, not Adafruit `239A`. Probing
  COM25 with Ctrl-C produced no REPL prompt.
  Conclusion: the board is running an **Arduino sketch** (earlephilhower arduino-pico core),
  not CircuitPython. This is not a wiring fault — nothing in this repo can run until
  CircuitPython is installed.
  Unblocked by: double-tap RESET (or hold BOOT while tapping RESET) to expose the `RPI-RP2`
  bootloader drive, then copying a CircuitPython `.uf2` onto it. `INFO_UF2.TXT` on that
  drive names the exact board model, which is what decides the correct `.uf2` — the
  `PicoArduino` descriptor is generic across RP2040 boards and does not confirm a KB2040.
- Background watcher armed (task `bq0e5lsno`) polling for an `RPI-RP2` or `CIRCUITPY` volume.

### 2026-08-01 — HARDWARE BRING-UP COMPLETE (B1, B4 unblocked)

The attached board was running an Arduino sketch. Identified it definitively from
`arduino-pico`'s `boards.txt` (`adafruit_kb2040.pid.0=0x8105`) rather than guessing —
`INFO_UF2.TXT` cannot identify an RP2040 board, because the bootloader is in the chip's
mask ROM and always reports `Model: Raspberry Pi RP2 / Board-ID: RPI-RP2`.

- Entered the UF2 bootloader with the Arduino **1200-baud touch** (double-tap RESET had not
  worked), installed **CircuitPython 10.2.1 for adafruit_kb2040**, verified the UF2 header
  (family `0xe48bff56`) before writing.
- `boot_out.txt`: `Adafruit CircuitPython 10.2.1 ... Adafruit KB2040 with rp2040`,
  UID `DF6114B5C37B432F` — matching the USB serial seen under Arduino, so same board.
- **B1 ANSWERED: `microcontroller.nvm` is 4096 bytes on real hardware.** The plan-time
  assumption held; stop condition 1 never triggered.
- **B4 DONE:** after a hard reset, two CDC ports enumerate (COM27 console, COM28 data), HID
  is keyboard + consumer control with the mouse correctly suppressed, and `boot_out.txt`
  records the boot.py line.
- Verified on hardware: autodetect picks the data port (COM28) unaided; `info`; `download`
  byte-identical to `examples/default.json`; `set`/`get` round-trip; `profile use`;
  `defaults`. **Persistence proven**: `dwell_ms` set to 1234, hard reset, read back 1234.
- Board left in factory state, `storage ok`, 204 / 4096 bytes.

#### Three bugs only hardware could find

1. `nvmstore.load()` did `bytes(self.nvm)`. `microcontroller.nvm` is an `nvm.ByteArray`:
   sized and sliceable but **not iterable**, so this raised `TypeError` and the firmware
   died on its first boot. Fixed to slice. The host tests used a plain `bytearray`, which
   *is* iterable — the test double is now a `FakeNvm` with `__iter__ = None` that reproduces
   the constraint, plus a test asserting the double still refuses iteration.
2. `Autodetect` opened every serial port, including Bluetooth ones. Opening an idle
   Bluetooth port blocks for minutes; a single `info` hung past 120s. It now skips non-USB
   ports, guarded by `portsHaveUSBMetadata` so cgo-less macOS (which has no USB metadata)
   still probes everything.
3. An interrupted run left its unread reply in the port buffer, and the next process read it
   as its own — `info` returned `OK 204`, the terminator of an earlier `read`. The client now
   drains before every command, making it self-resynchronising. Firmware also strips control
   characters from command lines, after a stray Ctrl-C turned `version` into
   `'\x03version'`.

Test count 137 → **156**. All three fixes have regression tests.

#### Default configuration changed (user request)

Profile 0 `colors` (active): tap = **Print Screen**; the eight colour slots type the name of
the colour they are showing — Red, Orange, Yellow, Green, Cyan, Blue, Violet, Magenta — one
per LED in the default chain, in the same order the startup sweep paints them. Profile 1
`media` keeps play/pause plus volume and track controls, and carries the delay step that
keeps the cross-language golden vector covering all four step types. 204 / 4096 bytes.

### 2026-08-01 — confirmed working by the operator; docs + CLI manual

- Operator confirmed the device works on hardware. Task 7 closed.
- `README.md` corrected against what actually happened during bring-up: bootloader entry now
  lists the 1200-baud touch (double-tap RESET did nothing on a board running Arduino), a
  warning that `INFO_UF2.TXT` cannot identify an RP2040 board, real `ports`/`info` output
  rather than idealised output, and a troubleshooting entry for a board with no CIRCUITPY
  drive. Added the "Out of the box" table for the `colors` profile.
- `docs/manual.md` — 13-page CLI reference: the colour-tap model, finding the board, exit
  status, every command with flags and examples, the configuration schema, the byte budget,
  and troubleshooting.
- `scripts/build-manual.py` renders it to `docs/kb2040ctl-manual.pdf` (pandoc + WeasyPrint,
  print CSS inline in the script). Committed both the source and the PDF; regenerate with
  `python scripts/build-manual.py`.
- Two new tests assert `docs/manual.md` documents exactly the CLI's registered commands, in
  both directions — matching the existing README guard, so a new command cannot ship with a
  manual that silently omits it.
- PDF emailed to the operator via SES from an `@jeremy.ninja` sender.

### 2026-08-01 — manual and tooling made cross-platform

The manual and the flashing story were Windows-shaped. Corrected:

- `docs/manual.md` grew an **Installing** chapter covering all three platforms: release
  asset per target, Windows SmartScreen / `Unblock-File`, macOS Gatekeeper quarantine
  (`xattr -d com.apple.quarantine`), and Linux serial permissions (`dialout`/`uucp`, plus a
  udev rule scoped to vendor `239a` that also sets `ID_MM_DEVICE_IGNORE`).
- "Finding the board" now documents port naming per platform (`COMn`,
  `/dev/cu.usbmodem*`, `/dev/ttyACM*`), and `ports` shows example output on each.
- Troubleshooting split into "any platform", Windows, macOS and Linux sections. The Linux
  ones cover the two genuine blockers: group permissions, and ModemManager holding
  `/dev/ttyACM*` for several seconds after plug-in.
- Noted that keystrokes are HID usage codes, so what a key produces depends on the host's
  layout, and that `WIN`/`CMD` are aliases for the same `GUI` modifier bit.
- 13 → **18 pages**.

**`scripts/flash.sh`** added — the macOS/Linux counterpart of `flash.ps1`. Finds CIRCUITPY
under `/Volumes`, `/media/$USER`, `/run/media/$USER`, `/media` or `/mnt`, takes `--drive` for
anything else, verifies `boot_out.txt`, installs libraries with circup, mirrors `src/`
(removing `singlekey/` first so a deleted module cannot linger), and `sync`s before
reporting success. Without it, Mac and Linux users had no way to flash at all.

**macOS port-selection bug fixed** in `internal/device/ports_basic.go` (the cgo-less build).
It now skips `/dev/tty.*` in favour of the `/dev/cu.*` twin — opening the tty variant of a
callout device blocks until carrier detect, which a USB CDC port never asserts, so autodetect
would have hung on macOS. Bluetooth ports are skipped and `usbmodem`/`usbserial` names are
tried first. All six targets still build with `CGO_ENABLED=0`.

### 2026-08-01 — autodetect made fast (measured, then fixed)

Answering "does the CLI find the port automatically?" turned up a measurable wart in what
had just shipped. Autodetect works, but it was paying the full 3-second command timeout on
the REPL console port before falling through to the config port:

    autodetect   3.98s / 3.73s / 3.60s
    -port COM28  0.44s

`autodetectFrom` now probes in two passes: 500 ms per candidate first, then the full
`DefaultTimeout`. The quick pass finds a healthy board (which replies in milliseconds) and
rules out dead ports cheaply; the patient pass remains because a binding with a `delay_ms`
step can occupy the firmware for up to ten seconds, so silence is not proof of the wrong
port. Measured after the change on the same board:

    autodetect   1.44s / 1.11s / 1.09s

The probe loop was extracted so it takes an opener function, and is covered by three tests
(picks the port that answers, still finds a board that misses the quick pass, gives up when
nothing answers) using a fake opener rather than real ports.

**Process note:** two earlier `python .replace()` source edits silently no-opped because the
search string did not match, and `go vet` passed either way because the old code was still
valid. Caught only by a later compile error. Use the `Edit` tool for source changes — it
fails loudly on a mismatch.

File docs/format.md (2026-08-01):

# kb2040-single-key — on-device binary format

**This file is authoritative.** Two implementations depend on it: the Go encoder/decoder in
`cli/internal/blob` and the CircuitPython decoder in `src/singlekey/blob.py`. They are
pinned together by golden vectors in `tests/fixtures/` — change this spec and both
implementations plus the fixtures must change together, or CI fails.

Format version: **1**.

## Conventions

- All multi-byte integers are **little-endian** and **unsigned**.
- `u8` = 1 byte, `u16` = 2 bytes.
- Offsets are measured in bytes from the **start of the blob**.
- Strings are UTF-8, length-prefixed, never NUL-terminated.

## Why binary

The whole configuration lives in `microcontroller.nvm`, which is ~4096 bytes on the RP2040.
Multiple profiles, each with up to 16 colour slots, each slot holding a multi-step sequence
that may contain typed text, does not fit as JSON. The format below is variable-length
throughout so the byte budget can be spent where the user wants it: a few large profiles or
many small ones.

The host-facing format is JSON; the Go CLI is the only thing that translates between them.
The device never parses JSON.

## Blob layout

```
offset  size          field
0       4             magic       "KB2K" (0x4B 0x42 0x32 0x4B)
4       1             fmt_ver     u8, currently 1
5       1             flags       u8, reserved, must be 0
6       1             active      u8, index of the active profile (< nprofiles)
7       1             nprofiles   u8, 1..8
8       2             blob_len    u16, total blob size in bytes, including magic and crc
10      2*nprofiles   offsets     u16[nprofiles], byte offset of each profile record
...     variable      profiles    the profile records, in index order
end-2   2             crc16       u16, CRC-16/CCITT-FALSE over bytes [0, end-2)
```

`crc16` is the last two bytes of the blob. Everything before it is covered by the checksum,
including the magic, `blob_len` and the offset table.

`blob_len` is what makes a blob **self-delimiting**. NVM is a fixed 4096-byte region and a
blob is almost always shorter, so a reader is handed the whole region and has no other way
to know where the blob ends — and it must know that before it can check the CRC, which sits
at the end. A decoder reads `blob_len` first, rejects it if it exceeds the buffer it was
given, truncates to it, and ignores everything after. The same field lets a `.bin` file on
disk stand alone.

### CRC-16/CCITT-FALSE

Polynomial `0x1021`, initial value `0xFFFF`, **no** input reflection, **no** output
reflection, final XOR `0x0000`. Check value: `CRC16("123456789") == 0x29B1`.

## Profile record

```
size          field
1             name_len    u8, 0..16
name_len      name        UTF-8
2             dwell_ms    u16, 100..10000 -- how long each colour slot is shown
2             tap_max_ms  u16, 20..2000   -- release under this is a tap, not a hold
1             overflow    u8, 0 wrap | 1 wrap_cancel | 2 clamp
1             ext_count   u8, 0..64  -- external WS2812 chain length, 0 disables it
1             brightness  u8, 0..255
1             idle_mode   u8, 0 off | 1 solid | 2 breathe | 3 rainbow
3             idle_color  u8[3], R G B
1             nslots      u8, 1..16 -- number of colour slots
variable      binding[0]  the TAP binding
variable      binding[1..nslots]  the colour slot bindings, in cycle order
```

A profile therefore always carries `nslots + 1` bindings: index 0 is the tap, indices
`1..nslots` are colour slots `0..nslots-1` in the order they are shown during a hold.

## Binding record

```
size          field
3             color       u8[3], R G B
1             nsteps      u8, 0..64  -- 0 is legal and means "do nothing"
variable      step[0..nsteps)
```

For the tap binding, `color` is what the LEDs show while the key is held inside the tap
window. For a slot binding, `color` is the colour shown during that slot — this is the
entire user interface of a colour tap.

## Step record

```
u8 type, then:

0  key       u8 keycode, u8 mods      -- press with modifiers, then release
1  text      u8 len, len bytes UTF-8  -- type the string
2  consumer  u16 code                 -- Consumer Control usage, press and release
3  delay     u16 ms                   -- wait, 0..10000
```

`keycode` is a USB HID keyboard usage ID (the values behind `adafruit_hid.keycode.Keycode`).

`mods` is the standard HID modifier bitmask:

| bit | 0 | 1 | 2 | 3 | 4 | 5 | 6 | 7 |
|---|---|---|---|---|---|---|---|---|
| | LCTRL | LSHIFT | LALT | LGUI | RCTRL | RSHIFT | RALT | RGUI |

`code` for a consumer step is a USB HID Consumer Control usage ID (the values behind
`adafruit_hid.consumer_control_code.ConsumerControlCode`).

## Timing model

`t` is milliseconds since the key was pressed.

- `t < tap_max_ms` at release → fire **binding 0** (the tap).
- Otherwise the hold is in colour-tap mode. With `u = t - tap_max_ms` and
  `raw = floor(u / dwell_ms)`, the displayed slot is:

| overflow | displayed slot |
|---|---|
| `wrap` (0) | `raw mod nslots` |
| `wrap_cancel` (1) | `k = raw mod (nslots + 1)`; slot `k` if `k < nslots`, else the **cancel** slot |
| `clamp` (2) | `min(raw, nslots - 1)` |

Releasing while slot `i` is displayed fires **binding `i + 1`**. Releasing on the
`wrap_cancel` cancel slot fires nothing; the LEDs are dark while it is displayed, which is
what makes it recognisable.

## Validation limits

An encoder must reject, and a decoder must not trust, anything outside these:

| field | range |
|---|---|
| `nprofiles` | 1..8 |
| `active` | `< nprofiles` |
| `name_len` | 0..16 |
| `dwell_ms` | 100..10000 |
| `tap_max_ms` | 20..2000 |
| `overflow` | 0..2 |
| `ext_count` | 0..64 |
| `nslots` | 1..16 |
| `nsteps` | 0..64 |
| text step `len` | 1..255 |
| delay step `ms` | 0..10000 |
| whole blob | ≤ NVM size (4096 on RP2040) |

## Decoder robustness

The device must never be bricked by a bad blob. `src/singlekey/blob.py` returns factory
defaults, with a machine-readable reason, on any of: NVM absent, all-`0x00`/all-`0xFF` NVM
(never written), bad magic, `fmt_ver` it does not understand, CRC mismatch, an offset
pointing outside the blob, or a record that runs past the end of the buffer. A decode
failure is reported by `version`/`info` rather than silently swallowed.

## Wire encoding

Blobs move over the serial port as **Ascii85**, btoa flavour: no `<~ ~>` wrapper, character
range `!`..`u` (ASCII 33–117). Lines are wrapped at 80 characters; decoders ignore newlines.
Both sides accept the `z` shorthand for an all-zero group, and **neither side emits it**.

That last rule is what makes an upload framable. With `z` suppressed, the encoded length is
a pure function of the input length:

```
encoded_len(n) = 5*(n/4) + (n%4 ? n%4 + 1 : 0)
```

so the receiver knows exactly how many characters a declared `write <len>` will take and
detects the end by counting. A terminator character was the obvious alternative and does not
work: every candidate (`.`, `!`, `~`) is itself legal Ascii85, and a final line can be a
single character, so a terminator is genuinely ambiguous rather than merely unlikely.

Go gets Ascii85 from stdlib `encoding/ascii85` (`cli/internal/wire` expands the `z` it
emits); CircuitPython has no equivalent, so `src/singlekey/a85.py` implements it. The two
are pinned by `tests/fixtures/default.a85`.

Ascii85 costs 25% overhead against base64's 33% — a full 4096-byte blob is ~5.1 KB on the
wire rather than ~5.5 KB.

## Serial protocol

Line-based, `\n`-terminated, on the **data** CDC port (`usb_cdc.data`), not the console.
Every command emits exactly one terminating `OK`, `OK <detail>`, or `ERR <reason>` line.

| command | effect |
|---|---|
| `help` | one line per command |
| `version` | `OK fw=<v> fmt=<n> nvm=<bytes> used=<bytes> profiles=<n> active=<n> status=<ok\|reason>` |
| `read` | Ascii85 blob, 80 chars per line, then `OK` |
| `write <len> <crc16>` | then exactly `encoded_len(len)` Ascii85 characters; see below |
| `profile <n>` | set the active profile and persist it |
| `test <profile> <binding>` | fire a binding on demand |
| `events on\|off` | stream `EV press`, `EV slot <i> <RRGGBB>`, `EV cancel`, `EV fire <binding>`, `EV release` |
| `defaults` | rewrite factory defaults to NVM |

### `write`

The header line declares the decoded byte count and `crc16` **of the decoded bytes** — that
is a transport check, independent of the CRC stored inside the blob, and it catches a
corrupted or truncated serial transfer before the blob is ever parsed. `crc16` may be
decimal or `0x`-prefixed.

A malformed header is answered immediately with `ERR`. A well-formed one produces **no
response**; the device then consumes Ascii85 characters until it has `encoded_len(len)` of
them, and only then answers with a single `OK written <n>` or `ERR <reason>`. That keeps the
"exactly one terminating line per command" rule intact for a multi-line command.

`write` is atomic. The transfer is buffered, then checked in order — character count, decode,
byte count, transport CRC, blob decode — and only a blob that passes every check is written
to NVM and made live. Any failure leaves the device exactly as it was.

An abandoned transfer (the host dies mid-upload) times out after 5 seconds of silence,
emits `ERR write timed out`, and returns the device to accepting commands. Without that, a
half-finished upload would wedge the config port until the board was replugged.

### `EV` lines

`EV` lines are emitted asynchronously while `events on` is in effect, so they can appear
between a command and its terminating `OK`. A client must skip lines beginning with `EV `
when reading a command response.

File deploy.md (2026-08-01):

# deploy.md — how this repo deploys (read me before touching infra or credentials)

This repo is part of **JeremyProffittOrg** and follows the org-wide deployment standard
(established 2026-07-05, see the private `credential-rotation` repo for the full audit/design).
Every agent — Claude Code, Copilot, Codex, or human — follows these rules exactly.

## The one deployment path

**Deployment = push/merge to `main`.** GitHub Actions runs the pipeline; the pipeline is the
only thing that touches AWS.

- **NEVER deploy from a local machine.** No `aws cloudformation deploy`, no `sam deploy`,
  no `sam sync`, no `cdk deploy`, no `aws s3 sync` to production buckets. If a deploy is
  needed and no pipeline exists, build/extend the GitHub Actions workflow instead.
- Verify a deploy by watching the run (`gh run watch <id>`); report a one-line summary
  ("Deploy: completed in 2m15s"), not the full log. Show detail only on failure.

## AWS authentication — OIDC only, no static keys

Workflows authenticate with the org-wide **`gha-deploy`** IAM role via GitHub OIDC.
The role ARN comes from the repo variable **`AWS_DEPLOY_ROLE_ARN`** (set at repo creation;
org-level variables do NOT reach private repos on our GitHub plan, so it must be repo-level).

The canonical job shape:

```yaml
jobs:
  deploy:
    runs-on: ubuntu-latest
    permissions:
      id-token: write     # required for OIDC
      contents: read      # use `write` only if the job pushes commits/releases
    steps:
      - uses: actions/checkout@v4
      - name: Configure AWS credentials (OIDC)
        uses: aws-actions/configure-aws-credentials@v4
        with:
          role-to-assume: ${{ vars.AWS_DEPLOY_ROLE_ARN }}
          role-session-name: gha-${{ github.event.repository.name }}-${{ github.run_id }}
          aws-region: us-east-1
```

- **NEVER add `aws-access-key-id` / `aws-secret-access-key` inputs** or `AWS_ACCESS_KEY_ID`
  env exports to a workflow. Never create IAM users or access keys for CI.
- Adding a `permissions:` block replaces the default grants — keep whatever write
  permissions the job already relies on.
- The role trusts `main`/`master`/`develop` branches, `v*` tags, and GitHub environments —
  PRs and feature branches deliberately cannot assume it.
- Target account is in the repo variable `DEPLOY_AWS_ACCOUNT`
  (759775734231 = jeremy.ninja · 584444171698 = caps/pappraisal · 231545823618 = artphotography).
- If the role is denied an `iam:PassRole` to a new AWS service, the fix goes in
  `credential-rotation/infra/github-oidc-deploy.yaml` (org repo), not in a per-repo key.

## Credentials — agents NEVER handle secret values

**Do not ask the user to paste a credential into chat. Do not echo, log, or commit secret
values. Do not put secrets in workflow files, samconfig.toml, or source.** GitHub secrets
are write-only; there is no legitimate reason for an agent to see a secret value.

To add or update a secret, run the script and let the **user type the value directly into
the terminal prompt** (it never enters the conversation):

```bash
./scripts/set-secret.sh SECRET_NAME            # prompts user (hidden input), pushes via gh
./scripts/set-secret.sh SECRET_NAME --file p   # multiline secrets (keys/certs) from a file
```

The script sets the secret on this repo, verifies `updated_at`, and prints only a
fingerprint. If a workflow needs a secret that doesn't exist yet: reference it as
`${{ secrets.NAME }}`, tell the user to run the script, and wait — never invent a value,
never stub around it.

**Non-secret configuration** (domains, ARNs, IDs, emails, usernames, regions, buckets) goes
in **variables**, not secrets: `gh variable set NAME --body "value"`. If a value would be
fine printed in a log, it is a variable.

Org-wide rotation is handled by the `credential-rotation` repo's manifest + `rotate-secrets.sh` —
don't build per-repo rotation machinery.

## Stack standards (mandatory)

- **Cost-allocation tags** on every stack, set ONCE at stack level in `samconfig.toml`
  (`tags = "..."` under `[default.deploy.parameters]`), never per-resource:
  `Project=<repo-name> CostCenter=<bucket> Environment=prod ManagedBy=sam DeployedVia=github-actions Owner=jeremy`
  (CostCenter buckets: caps, photography, mcp-servers, media, voice-ai, home-iot, utility.)
- **Lambda = arm64 (Graviton)** unless a dependency forces x86_64. For compiled runtimes,
  the build flags and `Architectures: [arm64]` MUST change together
  (Go: `GOOS=linux GOARCH=arm64 CGO_ENABLED=0`).
- **No secrets managers** (AWS Secrets Manager, Vault, …) — use Lambda env vars, SSM
  Parameter Store standard tier, or GitHub secrets.
- **No DynamoDB `Scan` on any serving path** (API/feed/list endpoints). Key lookups,
  `Query`, or a cached/S3-snapshot representation only.
- Production-only: assume no staging environment. Verify before you deploy.

## Repo bootstrap facts (filled in at creation)

| | |
|---|---|
| Repo | `JeremyProffittOrg/kb2040-single-key` |
| Domain | `kb2040-single-key.jeremy.ninja` |
| AWS account | `759775734231` (repo var `DEPLOY_AWS_ACCOUNT`) |
| Deploy role | repo var `AWS_DEPLOY_ROLE_ARN` |
| Pre-set variables | `ADMIN_USER, DOMAIN_NAME, HOSTED_ZONE_ID, CERTIFICATE_ARN, CERTIFICATE_ARN_US_EAST_2, CLOUDFORMATION_S3_BUCKET, DEPLOY_AWS_ACCOUNT, AWS_DEPLOY_ROLE_ARN` |
| Pre-set secrets | **none** — add only what a workflow actually references, via `scripts/set-secret.sh` |

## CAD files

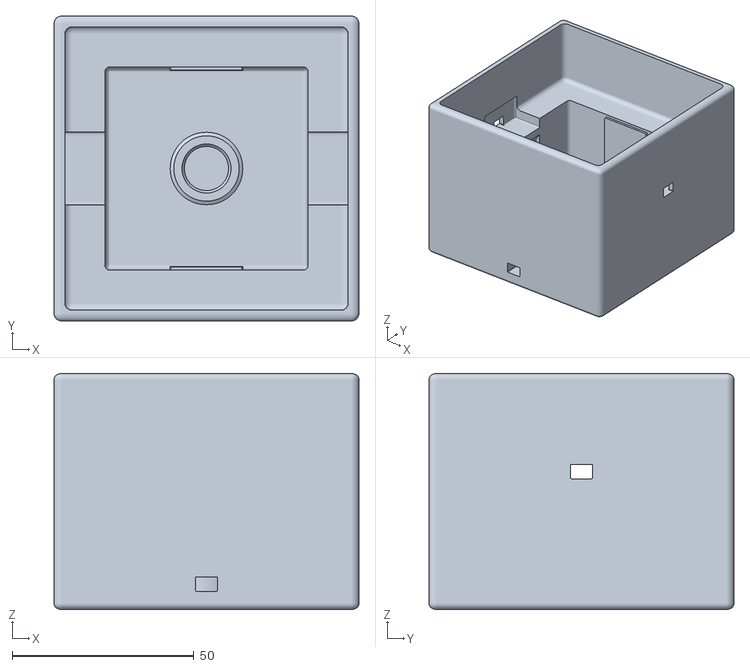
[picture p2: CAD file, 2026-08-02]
BigSwitchCase.stl
84.0 x 84.0 x 65.0

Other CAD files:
BigSwitchCase.scad

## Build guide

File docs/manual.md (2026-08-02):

---
title: kb2040ctl
subtitle: Command reference for the kb2040-single-key colour-tap keyboard
version: 0.1.0
---

# About this manual

`kb2040ctl` configures a **kb2040-single-key** board: an Adafruit KB2040 with one mechanical
switch and a chain of WS2812 RGB LEDs, which enumerates as a USB keyboard *and* a second USB
serial port used only for configuration.

The tool runs on **Windows, macOS and Linux**, on both x86-64 and arm64. It is a single
static binary with no runtime to install. Where the three platforms genuinely differ — how
serial ports are named, what permissions are needed, how a downloaded binary is unblocked —
this manual says so; everywhere else the commands are identical.

The binary format and serial protocol are specified separately in `docs/format.md`; the
hardware, wiring and firmware are covered in `README.md`.

Verified against an Adafruit KB2040 running CircuitPython 10.2.1.

# The colour tap, in one page

A single key can only do one thing — unless time and colour become extra inputs.

**Tap** the key (press and release quickly) and the profile's *tap* binding fires.

**Hold** it and, once past the tap window, the LEDs cycle through colours one per second.
Each colour is a **slot**. Release while a colour is showing and *that* slot fires.

```
press
  |<-- tap window -->|<-- slot 0 --->|<-- slot 1 --->|<-- slot 2 --->|
  |     250 ms       |    1000 ms    |    1000 ms    |    1000 ms    |
  |     (white)      |     (red)     |   (orange)    |   (yellow)    |
  0                 250            1250            2250            3250 ms

  release here...    ...or here      ...or here      ...or here
  -> tap binding     -> slot 0       -> slot 1       -> slot 2
```

The LED is the entire user interface: hold, watch for the colour you want, release.

`tap_max_ms` (default 250) and `dwell_ms` (default 1000) are per-profile settings.

## Past the last colour

The per-profile `overflow` setting decides what a long hold does:

| `overflow` | behaviour |
|---|---|
| `wrap` | back to the first colour, cycling forever. Overshoot is recoverable — keep holding. |
| `wrap_cancel` | as `wrap`, but with one **dark** slot per rotation. Release while the LEDs are off and nothing fires. This is the escape hatch. |
| `clamp` | stay on the last colour indefinitely. Forgiving of long holds, but an earlier slot can only be reached by releasing and starting again. |

## Bindings and steps

Every binding — the tap and each colour slot — is a **sequence** of steps, run in order:

| step | example | effect |
|---|---|---|
| key | `{ "key": "M", "mods": ["CTRL", "SHIFT"] }` | press with modifiers, then release |
| text | `{ "text": "On my way." }` | type the string |
| media | `{ "consumer": "PLAY_PAUSE" }` | a Consumer Control usage |
| delay | `{ "delay_ms": 200 }` | wait before the next step |

## Profiles

The board stores several complete configurations, one active at a time. The factory
configuration ships with two.

**Profile 0, `colors`** (active) is self-describing — a tap sends Print Screen, and each
colour slot types the name of the colour it is showing:

| Gesture | Colour | Action |
|---|---|---|
| tap | white | Print Screen |
| slot 0 | `#FF0000` | types `Red` |
| slot 1 | `#FF6000` | types `Orange` |
| slot 2 | `#FFC000` | types `Yellow` |
| slot 3 | `#00FF00` | types `Green` |
| slot 4 | `#00FFFF` | types `Cyan` |
| slot 5 | `#0000FF` | types `Blue` |
| slot 6 | `#8000FF` | types `Violet` |
| slot 7 | `#FF00FF` | types `Magenta` |

**Profile 1, `media`** is play/pause on tap, with mute, volume and track controls on the
colour slots, and a final slot that screenshots, waits, and pastes.

# Installing

Download the binary for your platform from the releases page, or build from source. There is
no runtime dependency either way.

| Platform | Release asset |
|---|---|
| Windows (Intel/AMD) | `kb2040ctl_<version>_windows_amd64.exe` |
| Windows (Arm) | `kb2040ctl_<version>_windows_arm64.exe` |
| macOS (Apple silicon) | `kb2040ctl_<version>_darwin_arm64` |
| macOS (Intel) | `kb2040ctl_<version>_darwin_amd64` |
| Linux (Intel/AMD) | `kb2040ctl_<version>_linux_amd64` |
| Linux (Arm, e.g. Raspberry Pi) | `kb2040ctl_<version>_linux_arm64` |

`SHA256SUMS` is published alongside them.

## Windows

Rename the download to `kb2040ctl.exe` and put it somewhere on your `PATH`. Nothing else is
required: Windows 10 and 11 bind USB CDC devices to the built-in `usbser.sys` driver, so the
board needs no driver install.

SmartScreen may warn that the publisher is unknown, because the binary is not code-signed.
Choose *More info* → *Run anyway*, or unblock it once in PowerShell:

```powershell
Unblock-File .\kb2040ctl.exe
```

## macOS

Make it executable, and clear the quarantine flag that Gatekeeper puts on anything
downloaded from a browser:

```bash
chmod +x kb2040ctl_0.1.0_darwin_arm64
xattr -d com.apple.quarantine kb2040ctl_0.1.0_darwin_arm64
sudo mv kb2040ctl_0.1.0_darwin_arm64 /usr/local/bin/kb2040ctl
```

Without the `xattr` step macOS refuses to run it — *"cannot be opened because the developer
cannot be verified"*. No driver or extension is needed; serial access requires no special
permission.

## Linux

```bash
chmod +x kb2040ctl_0.1.0_linux_amd64
sudo mv kb2040ctl_0.1.0_linux_amd64 /usr/local/bin/kb2040ctl
```

**Serial port permissions are the one extra step.** On most distributions `/dev/ttyACM*` is
owned by root and the `dialout` group, so a normal user gets *permission denied* until they
join it:

```bash
sudo usermod -aG dialout "$USER"      # Debian, Ubuntu, Raspberry Pi OS
sudo usermod -aG uucp "$USER"         # Arch, and some Fedora setups
```

Log out and back in for the new group to apply — `newgrp dialout` works for the current
shell in the meantime. Check with `groups`.

If you would rather not add a group membership, a udev rule scoped to Adafruit's vendor ID
does the same job and also stops ModemManager from interfering (see *Troubleshooting*):

```
# /etc/udev/rules.d/99-kb2040.rules
SUBSYSTEM=="tty", ATTRS{idVendor}=="239a", MODE="0660", GROUP="plugdev", \
  ENV{ID_MM_DEVICE_IGNORE}="1"
```

```bash
sudo udevadm control --reload-rules && sudo udevadm trigger
```

## Building from source

Requires Go 1.24 or newer. No cgo, so cross-compiling needs nothing beyond the toolchain:

```bash
go build -o kb2040ctl ./cli/cmd/kb2040ctl
```

On macOS a native build (cgo enabled by default) additionally reads USB descriptors through
IOKit, so `kb2040ctl ports` can show vendor and product IDs. The released macOS binaries are
built without cgo and show port names only; this affects the display, not the ability to
find the board.

## Getting the firmware onto the board

Covered fully in `README.md`. In short, once the board mounts as `CIRCUITPY`:

```powershell
pwsh scripts/flash.ps1        # Windows
```

```bash
scripts/flash.sh              # macOS and Linux
```

Both install the CircuitPython libraries with `circup` and copy `src/` onto the board. Then
**unplug and replug** — `boot.py` only takes effect on a hard reset, and it is what creates
the configuration serial port.

# Using the CLI

## Synopsis

```
kb2040ctl <command> [flags] [arguments]
```

Run `kb2040ctl` with no arguments for a summary, or `kb2040ctl <command> -h` for one
command's flags.

## Finding the board

Every command that talks to the board accepts `-port`:

```bash
kb2040ctl info -port COM28                    # Windows
kb2040ctl info -port /dev/cu.usbmodem1101     # macOS
kb2040ctl info -port /dev/ttyACM1             # Linux
```

**Without `-port`, every command finds the board on its own.** Each candidate serial port is
asked for its version, and the one that answers is the board. No configuration, no saved
state, no udev alias — plug it in and run the command.

This is deliberate rather than matching a USB ID. The board exposes *two* CDC ports — the
CircuitPython REPL console and the configuration port — with identical vendor and product
IDs. Only the second answers this protocol, so the ID cannot tell them apart. Probing also
means a board with customised USB identification still works.

Ports are tried in a sensible order — on Windows and Linux, ones belonging to Adafruit's USB
vendor ID first — so in practice the board is usually the first or second port opened.

Scanning happens in two passes. The first gives each port half a second, which is ample
because a healthy board replies in milliseconds; this is what keeps autodetection down to
about a second in total rather than several. If nothing answers, a second, patient pass
allows the full timeout, because a silent port is not proof of the wrong port — a binding
containing a `delay_ms` step can occupy the firmware for up to ten seconds, during which the
real board is merely busy.

Autodetection costs roughly a second per command. Passing `-port` skips it and cuts that to
about a tenth of that, which is worth doing in a script that runs many commands:

```bash
PORT=$(kb2040ctl ports | awk '/^->/ {print $2}')
kb2040ctl -port "$PORT" info
```

Ports already held open by another program are skipped rather than waited on, so a serial
monitor left running elsewhere slows nothing down.

### What the two ports look like

| Platform | Typical names | Notes |
|---|---|---|
| Windows | `COM27`, `COM28` | numbers are assigned by Windows and are not predictable |
| macOS | `/dev/cu.usbmodem1101`, `/dev/cu.usbmodem1103` | use the `cu.` names, never `tty.` |
| Linux | `/dev/ttyACM0`, `/dev/ttyACM1` | numbering depends on what else is plugged in |

Of each pair the lower is normally the REPL console and the higher the configuration port,
but do not rely on it — `kb2040ctl ports` marks the right one.

On macOS, only `/dev/cu.*` ports are considered. Opening the `/dev/tty.*` twin of a callout
device blocks until carrier detect is asserted, which never happens for a USB CDC port, so
probing it would hang. Bluetooth ports are skipped on every platform for the same class of
reason — on Windows, opening an idle Bluetooth serial port can block for minutes.

## Exit status

| Status | Meaning |
|---|---|
| 0 | success |
| 1 | the command failed; the reason is printed to standard error |
| 2 | the command was not recognised, or its arguments were wrong |

Machine-readable output (`download`, `get`) goes to standard output; progress and
diagnostics go to standard error, so `kb2040ctl download > config.json` is safe on every
platform.

# Commands

## ports

```
kb2040ctl ports
```

Lists every serial port and marks the board with `->`.

```console
$ kb2040ctl ports                     # Windows
   COM27        USB Serial Device (COM27)  [USB 239A:8106]
-> COM28        USB Serial Device (COM28)  [USB 239A:8106]
   COM3         Standard Serial over Bluetooth link (COM3)
```

```console
$ kb2040ctl ports                     # Linux
   /dev/ttyACM0   KB2040 Single Key  [USB 239a:8106]
-> /dev/ttyACM1   KB2040 Single Key  [USB 239a:8106]
```

```console
$ kb2040ctl ports                     # macOS (released build, no cgo)
   /dev/cu.usbmodem1101   (no product name)
-> /dev/cu.usbmodem1103   (no product name)
```

If no board answers, the reason is printed after the list.

## info

```
kb2040ctl info [-port PORT]
```

Firmware version, storage use and the profile list. The active profile is marked `*`.

```console
$ kb2040ctl info
port       COM28
firmware   0.1.0 (format 1)
storage    204 / 4096 bytes used (3892 free)

* 0  colors           8 slots, 1000ms dwell, wrap overflow, 8 LEDs
  1  media            6 slots, 1000ms dwell, wrap_cancel overflow, 8 LEDs
```

A `status` line appears only when the board could **not** read its stored configuration and
fell back to the factory defaults:

| status | meaning |
|---|---|
| `blank` | nothing has ever been written to NVM |
| `corrupt: …` | something was there but failed to decode; the reason follows |
| `no-nvm` | the board has no non-volatile memory; configuration is RAM-only |

Uploading any configuration clears it.

## download

```
kb2040ctl download [-port PORT] [-p N] [-o FILE]
```

Saves the board's configuration as JSON. Writes to standard output unless `-o` is given.

| Flag | Meaning |
|---|---|
| `-p N` | download only profile *N* rather than the whole device |
| `-o FILE` | write to a file instead of standard output |

```console
$ kb2040ctl download -o mine.json
wrote mine.json (3061 bytes of JSON)

$ kb2040ctl download -p 0 -o colors.json
```

A single-profile file is the right input for `upload -p N`.

## upload

```
kb2040ctl upload [-port PORT] [-p N] FILE
```

Sends a configuration to the board.

| Flag | Meaning |
|---|---|
| `-p N` | replace only profile *N*, leaving the others untouched |

```console
$ kb2040ctl upload mine.json
uploaded 204 bytes (204 / 4096 used, 3892 free)

$ kb2040ctl upload -p 1 examples/meetings.json
```

The file is validated and the byte budget checked **before** anything is sent, and the board
checks both again before committing. A configuration that does not fit is refused at both
ends and the board is left exactly as it was.

Uploads are atomic. The transfer is buffered and checked in order — character count, decode,
byte count, transport checksum, then configuration decode — and only a configuration that
passes every check is stored.

## get

```
kb2040ctl get [-port PORT] PATH
```

Prints one value from the board's configuration as JSON.

Paths are dot-separated; a numeric segment indexes a list.

```console
$ kb2040ctl get profiles.0.dwell_ms
1000
$ kb2040ctl get profiles.0.slots.3.color
"#00FF00"
$ kb2040ctl get profiles.0.tap.steps.0
{"key":"PRINT_SCREEN"}
```

## set

```
kb2040ctl set [-port PORT] PATH VALUE
```

Changes one value and uploads the result.

```console
$ kb2040ctl set profiles.0.dwell_ms 1500
$ kb2040ctl set profiles.0.slots.2.color "#00FF80"
$ kb2040ctl set profiles.0.slots.0.steps.0.text "Back in five."
$ kb2040ctl set profiles.0.overflow clamp
$ kb2040ctl set active 1
```

`set` downloads the configuration, applies the edit, validates it and uploads the whole
thing. The board has no field-level write on purpose: the configuration is only ever stored
as a complete, checksummed unit, so a half-applied configuration cannot exist.

The type already stored at the path decides how the argument is read. A name of `2024` stays
the string `"2024"`; `dwell_ms 1500` becomes the number 1500; `quick` where a number belongs
is rejected. Lists and objects are given as JSON:

```console
$ kb2040ctl set profiles.0.tap.steps '[{"key":"F5"},{"delay_ms":50}]'
```

In PowerShell, single quotes work the same way; `cmd.exe` needs double quotes with the inner
ones escaped, so a JSON value is easier from PowerShell.

Errors name what is available:

```console
$ kb2040ctl set profiles.0.dwel_ms 1500
kb2040ctl set: profiles.0 has no field "dwel_ms"; it has: brightness, dwell_ms,
ext_count, idle_color, idle_mode, name, overflow, slots, tap, tap_max_ms
```

## profile

```
kb2040ctl profile [-port PORT] list
kb2040ctl profile [-port PORT] use N
```

Lists the profiles, or switches the active one. Switching is persistent.

```console
$ kb2040ctl profile use 1
active profile is now 1
```

## test

```
kb2040ctl test [-port PORT] PROFILE BINDING
```

Fires a binding immediately, without touching the key. Binding 0 is the tap; 1 upwards are
the colour slots.

```console
$ kb2040ctl test 0 4
fired 1 step(s)
```

This sends **real keystrokes to whatever window has focus.** A text binding will type into
your terminal if that is where the cursor is. Use it to separate a wiring or timing problem
from a configuration problem, with the cursor somewhere harmless.

## watch

```
kb2040ctl watch [-port PORT]
```

Streams key and colour-slot events live. Ctrl-C stops it.

```console
$ kb2040ctl watch
Watching. Tap and hold the key; press Ctrl-C to stop.
press
slot 0 FF0000
slot 1 FF6000
slot 2 FFC000
release
fire 3
```

| Event | Meaning |
|---|---|
| `press` | key went down |
| `slot N RRGGBB` | the hold advanced to slot *N*, showing that colour |
| `cancel` | the hold reached the dark `wrap_cancel` slot |
| `release` | key came up |
| `fire N` | binding *N* ran |
| `error …` | a binding raised; the configuration port stays alive |

This is the tool for tuning timing. Overshooting slots means `dwell_ms` is too short; a
deliberate tap landing on slot 0 means `tap_max_ms` is too short.

## validate

```
kb2040ctl validate [-p] FILE
```

Checks a configuration file and reports the byte budget. **No board required** — useful in
an editor loop or in CI.

| Flag | Meaning |
|---|---|
| `-p` | the file holds a single profile rather than a whole device configuration |

```console
$ kb2040ctl validate examples/default.json
examples/default.json is valid: 2 profile(s), 204 / 4096 bytes (3892 free)
  0  colors           8 slots, 115 bytes
  1  media            6 slots, 73 bytes
```

## defaults

```
kb2040ctl defaults [-port PORT] [-y]
```

Restores the factory configuration, replacing **every** profile. Asks for confirmation
unless `-y` is given. Download a copy first if the current configuration is worth keeping.

## keys

```
kb2040ctl keys [media]
```

Lists every key name a configuration may use, or with `media`, every Consumer Control name.
Needs no board.

## version

```
kb2040ctl version
```

Prints the tool's own version.

# Configuration file format

```json
{
  "format": 1,
  "active": 0,
  "profiles": [
    {
      "name": "colors",
      "dwell_ms": 1000,
      "tap_max_ms": 250,
      "overflow": "wrap",
      "ext_count": 8,
      "brightness": 64,
      "idle_mode": "breathe",
      "idle_color": "#001018",
      "tap":   { "color": "#FFFFFF", "steps": [ { "key": "PRINT_SCREEN" } ] },
      "slots": [
        { "color": "#FF0000", "steps": [ { "text": "Red" } ] },
        { "color": "#FF6000", "steps": [ { "text": "Orange" } ] }
      ]
    }
  ]
}
```

Files are plain UTF-8 JSON and move between platforms unchanged; line endings do not matter.

## Profile fields

| Field | Range | Meaning |
|---|---|---|
| `name` | ≤ 16 bytes | shown by `info` and `profile list` |
| `dwell_ms` | 100–10000 | how long each colour is displayed |
| `tap_max_ms` | 20–2000 | release under this counts as a tap |
| `overflow` | `wrap`, `wrap_cancel`, `clamp` | behaviour past the last colour |
| `ext_count` | 0–64 | external WS2812 chain length; 0 disables it |
| `brightness` | 0–255 | applies to every LED |
| `idle_mode` | `off`, `solid`, `breathe`, `rainbow` | animation when the key is idle |
| `idle_color` | `#RRGGBB` | used by `solid` and `breathe` |
| `tap` | binding | fired by a quick tap |
| `slots` | 1–16 bindings | the colour slots, in cycle order |

Up to **8** profiles, subject to the byte budget.

## Binding and step fields

A binding is `{ "color": "#RRGGBB", "steps": [ … ] }`. A step sets **exactly one** of:

| Field | Type | Notes |
|---|---|---|
| `key` | name | with optional `mods` |
| `text` | string | 1–255 bytes |
| `consumer` | name | Consumer Control usage |
| `delay_ms` | 0–10000 | wait |

`mods` accompanies `key` only and accepts `CTRL`, `SHIFT`, `ALT`, `GUI`, and the
`R`-prefixed right-hand forms. `WIN` and `CMD` are accepted as aliases for `GUI`, which is
the same HID modifier bit on every platform — the host decides what it means. Run
`kb2040ctl keys` for key names and `kb2040ctl keys media` for media names. An unrecognised
name is rejected with a list of valid ones. A numeric form such as `0x68` is also accepted
for a raw HID usage ID.

Up to 64 steps per binding.

Keystrokes are sent as HID usage codes, so what a key produces depends on the **host's**
keyboard layout. Text steps are typed via a US layout; on a host set to another layout,
punctuation in a text step may not come out as written.

## The byte budget

The whole configuration lives in the RP2040's **4096-byte** non-volatile region. That is
what lets it persist while the `CIRCUITPY` drive stays writable from your computer.

There is no fixed per-profile limit — spend the space as you like. As a rule of thumb, a
slot with a key or media action costs about 8 bytes, and a slot that types a sentence costs
about 6 bytes plus the length of the text. The two-profile factory configuration uses 204
bytes, leaving room for roughly thirty more profiles of that size.

`validate` and `upload` both report usage, and an oversized configuration is refused before
anything is sent.

# Troubleshooting

## Any platform

**`no kb2040-single-key found`.** Either the board is not running this firmware, or another
program already holds the port — a serial monitor, the Mu editor, the Arduino IDE. Close it,
or pass `-port` explicitly.

**Only one serial port appears.** `boot.py` has not run. It takes effect only on a *hard*
reset: unplug and replug, or press the reset button. A soft reload is not enough.

**`info` shows a `status` that is not `ok`.** The board could not read its stored
configuration and is running the factory defaults. `blank` is normal on a board that has
never been configured. Uploading any configuration clears it.

**The LEDs work but the key does nothing.** The switch is not reaching `D4`/`GND`. Run
`kb2040ctl watch` — no `press` line means the firmware never sees the key.

**The key fires the wrong slot.** Run `kb2040ctl watch` and hold the key. If the slots
advance faster than you can react, raise `dwell_ms`; if a quick tap registers as slot 0,
raise `tap_max_ms`.

**Nothing at all on the LEDs at startup.** The firmware is not running. Check the REPL on the
*console* serial port for a traceback — a missing library is the usual cause.

## Windows

**SmartScreen blocks the binary.** It is not code-signed. *More info* → *Run anyway*, or
`Unblock-File .\kb2040ctl.exe`.

**A command hangs for a long time.** Older builds probed every serial port, including
Bluetooth ones, which can block for minutes. Current builds probe only USB ports; if you are
on an older binary, pass `-port` explicitly.

## macOS

**"cannot be opened because the developer cannot be verified".** Gatekeeper quarantine.
Clear it with `xattr -d com.apple.quarantine ./kb2040ctl`.

**`permission denied` when running it.** Missing the executable bit: `chmod +x ./kb2040ctl`.

**A command hangs.** Check you are not pointing `-port` at a `/dev/tty.*` name. Use the
`/dev/cu.*` twin; the `tty.` variant waits for carrier detect that a USB CDC port never
asserts. Autodetect already avoids them.

**`ports` shows no vendor or product IDs.** Expected on the released macOS binaries, which
are built without cgo and so cannot read USB descriptors. Identification is unaffected.
Build from source natively if you want the IDs.

## Linux

**`permission denied` opening `/dev/ttyACM1`.** Your user is not in the port's group. Add
yourself to `dialout` (Debian, Ubuntu, Raspberry Pi OS) or `uucp` (Arch, some Fedora), then
log out and back in:

```bash
sudo usermod -aG dialout "$USER"
```

Confirm with `groups`, and check the port's owner with `ls -l /dev/ttyACM*`.

**The first command after plugging in fails, then it works.** ModemManager probes new
`/dev/ttyACM*` devices for a few seconds, assuming they might be a cellular modem, and holds
the port while it does. Install the udev rule in *Installing → Linux* to exempt the board,
or if you have no modems at all:

```bash
sudo systemctl mask ModemManager
```

**No `CIRCUITPY` volume when flashing.** Many minimal or headless installs do not automount
removable media. Find it with `lsblk -o NAME,LABEL,MOUNTPOINT`, mount it, and pass the path:

```bash
scripts/flash.sh --drive /mnt/CIRCUITPY
```

**`kb2040ctl: command not found` after moving it to `/usr/local/bin`.** That directory is on
the default `PATH` on most distributions but not all; check with `echo $PATH`.

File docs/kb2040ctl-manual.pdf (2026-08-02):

# kb2040ctl

Command reference for the kb2040-single-key colour-tap keyboard

Version 0.1.0
Adafruit KB2040 · CircuitPython github.com/JeremyProffittOrg/kb2040-single-key

# About this manual

kb2040ctl configures a kb2040-single-key board: an Adafruit KB2040 with one mechanical switch and a chain of WS2812 RGB LEDs, which enumerates as a USB keyboard and a second USB serial port used only for configuration.
The tool runs on Windows, macOS and Linux, on both x86-64 and arm64. It is a single static binary with no runtime to install. Where the three platforms genuinely differ — how serial ports are named, what permissions are needed, how a downloaded binary is unblocked — this manual says so; everywhere else the commands are identical.
The binary format and serial protocol are specified separately in | docs/format.md ; the hardware, wiring
and firmware are covered in | README.md .
Verified against an Adafruit KB2040 running CircuitPython 10.2.1.
2 | kb2040ctl

# The colour tap, in one page

A single key can only do one thing — unless time and colour become extra inputs.
Tap the key (press and release quickly) and the profile's tap binding fires.
Hold it and, once past the tap window, the LEDs cycle through colours one per second. Each colour is a slot. Release while a colour is showing and that slot fires.

press
|<-- tap window -->|<-- slot 0 --->|<-- slot 1 --->|<-- slot 2 --->|
| | 250 ms | | | 1000 ms | | | 1000 ms | | | 1000 ms | |
| | (white) | | | (red) | | | (orange) | | | (yellow) | |
0 | | 250 | | 1250 | | 2250 | | 3250 ms
release here... | ...or here | ...or here | ...or here
-> tap binding | -> slot 0 | -> slot 1 | -> slot 2

The LED is the entire user interface: hold, watch for the colour you want, release.
tap_max_ms | (default 250) and | dwell_ms | (default 1000) are per-profile settings.

## Past the last colour

The per-profile | overflow | setting decides what a long hold does:
overflow | behaviour
wrap | back to the first colour, cycling forever. Overshoot is recoverable — keep holding.
wrap_cancel | as | wrap , but with one dark slot per rotation. Release while the LEDs are off and nothing fires. This
is the escape hatch.
clamp | stay on the last colour indefinitely. Forgiving of long holds, but an earlier slot can only be reached
by releasing and starting again.

## Bindings and steps

Every binding — the tap and each colour slot — is a sequence of steps, run in order:

step | example | | | | | | effect
key | { "key": "M", "mods": ["CTRL", "SHIFT"] } | press with modifiers, then release
text | { "text": "On my way." } | type the string
media | { "consumer": "PLAY_PAUSE" } | a Consumer Control usage
delay | { "delay_ms": 200 } | wait before the next step

## Profiles

The board stores several complete configurations, one active at a time. The factory configuration ships with two.
Profile 0, | colors | (active) is self-describing — a tap sends Print Screen, and each colour slot types the
name of the colour it is showing:
Gesture | Colour | Action
tap | white | Print Screen
slot 0 | #FF0000 | types | Red
slot 1 | #FF6000 | types | Orange
slot 2 | #FFC000 | types | Yellow
slot 3 | #00FF00 | types | Green
slot 4 | #00FFFF | types | Cyan
slot 5 | #0000FF | types | Blue
slot 6 | #8000FF | types | Violet
slot 7 | #FF00FF | types | Magenta
Profile 1, | media | is play/pause on tap, with mute, volume and track controls on the colour slots, and a
final slot that screenshots, waits, and pastes.

# Installing

Download the binary for your platform from the releases page, or build from source. There is no runtime dependency either way.

Platform | | Release asset
Windows (Intel/AMD) | kb2040ctl_<version>_windows_amd64.exe
Windows (Arm) | kb2040ctl_<version>_windows_arm64.exe
macOS (Apple silicon) | kb2040ctl_<version>_darwin_arm64
macOS (Intel) | kb2040ctl_<version>_darwin_amd64
Linux (Intel/AMD) | kb2040ctl_<version>_linux_amd64
Linux (Arm, e.g. Raspberry Pi) | kb2040ctl_<version>_linux_arm64
SHA256SUMS | is published alongside them.

## Windows

Rename the download to | kb2040ctl.exe | and put it somewhere on your | PATH . Nothing else is
required: Windows 10 and 11 bind USB CDC devices to the built-in | usbser.sys | driver, so the board
needs no driver install.
SmartScreen may warn that the publisher is unknown, because the binary is not code-signed. Choose More info → Run anyway, or unblock it once in PowerShell:

Unblock-File .\kb2040ctl.exe

## macOS

Make it executable, and clear the quarantine flag that Gatekeeper puts on anything downloaded from a

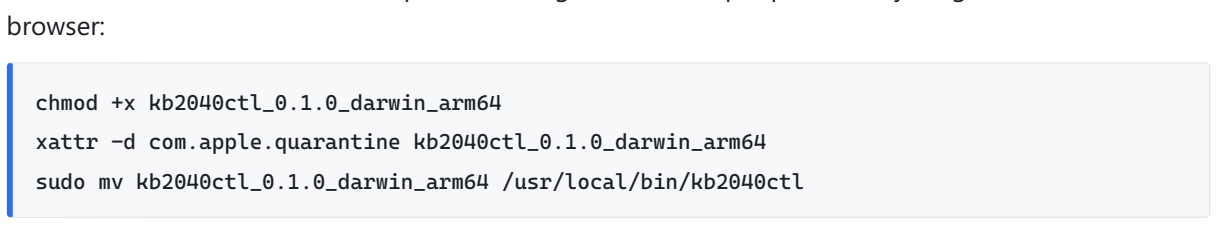
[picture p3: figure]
browser:; chmod +x kb2040ctl_0.1.0_darwin_arm64; xattr -d com.apple.quarantine kb2040ctl_0.1.0_darwin_arm64; sudo mv kb2040ctl_0.1.0_darwin_arm64 /usr/local/bin/kb2040ctl

Without the | xattr | step macOS refuses to run it — "cannot be opened because the developer cannot be
verified". No driver or extension is needed; serial access requires no special permission.

## Linux

Serial port permissions are the one extra step. On most distributions | /dev/ttyACM* | is owned by root
and the | dialout | group, so a normal user gets permission denied until they join it:
sudo usermod -aG dialout "$USER" | # Debian, Ubuntu, Raspberry Pi OS
sudo usermod -aG uucp "$USER" | # Arch, and some Fedora setups
Log out and back in for the new group to apply — | newgrp dialout | works for the current shell in the
meantime. Check with | groups .
If you would rather not add a group membership, a udev rule scoped to Adafruit's vendor ID does the same job and also stops ModemManager from interfering (see Troubleshooting):

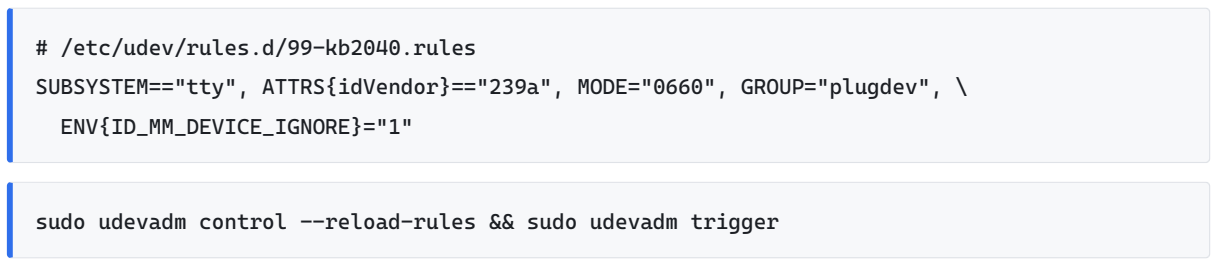
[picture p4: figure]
# /etc/udev/rules.d/99-kb2040.rules; SUBSYSTEM=="tty", ATTRS{idVendor}=="239a", MODE="0660", GROUP="plugdev", \; ENV{ID_MM_DEVICE_IGNORE}="1"

sudo udevadm control --reload-rules && sudo udevadm trigger

## Building from source

Requires Go 1.24 or newer. No cgo, so cross-compiling needs nothing beyond the toolchain:

go build -o kb2040ctl ./cli/cmd/kb2040ctl

On macOS a native build (cgo enabled by default) additionally reads USB descriptors through IOKit, so kb2040ctl ports can show vendor and product IDs. The released macOS binaries are built without cgo and show port names only; this affects the display, not the ability to find the board.

## Getting the firmware onto the board

Covered fully in | README.md . In short, once the board mounts as | CIRCUITPY :
Both install the CircuitPython libraries with | circup | and copy | src/ | onto the board. Then unplug and
replug — | boot.py | only takes effect on a hard reset, and it is what creates the configuration serial port.

# Using the CLI

## Synopsis

kb2040ctl <command> [flags] [arguments]

Run | kb2040ctl | with no arguments for a summary, or | kb2040ctl <command> -h | for one command's
flags.

## Finding the board

Every command that talks to the board accepts | -port :
Without | -port , every command finds the board on its own. Each candidate serial port is asked for its
version, and the one that answers is the board. No configuration, no saved state, no udev alias — plug it in and run the command.
This is deliberate rather than matching a USB ID. The board exposes two CDC ports — the CircuitPython REPL console and the configuration port — with identical vendor and product IDs. Only the second answers this protocol, so the ID cannot tell them apart. Probing also means a board with customised USB identification still works.
Ports are tried in a sensible order — on Windows and Linux, ones belonging to Adafruit's USB vendor ID first — so in practice the board is usually the first or second port opened.
Scanning happens in two passes. The first gives each port half a second, which is ample because a healthy board replies in milliseconds; this is what keeps autodetection down to about a second in total rather than several. If nothing answers, a second, patient pass allows the full timeout, because a silent
port is not proof of the wrong port — a binding containing a | delay_ms | step can occupy the firmware
for up to ten seconds, during which the real board is merely busy.
Autodetection costs roughly a second per command. Passing | -port | skips it and cuts that to about a
tenth of that, which is worth doing in a script that runs many commands:
PORT=$(kb2040ctl ports | awk '/^->/ {print $2}')

Ports already held open by another program are skipped rather than waited on, so a serial monitor left running elsewhere slows nothing down.

What the two ports look like

Platform | Typical names | | Notes
Windows | COM27 , | COM28 | numbers are assigned by Windows and are not
predictable
macOS | /dev/cu.usbmodem1101 , | /dev/cu.usbmodem1103 | use the | cu. | names, never | tty.
Linux | /dev/ttyACM0 , | /dev/ttyACM1 | numbering depends on what else is plugged in
Of each pair the lower is normally the REPL console and the higher the configuration port, but do not
rely on it — | kb2040ctl ports | marks the right one.
On macOS, only | /dev/cu.* | ports are considered. Opening the | /dev/tty.* | twin of a callout device
blocks until carrier detect is asserted, which never happens for a USB CDC port, so probing it would hang. Bluetooth ports are skipped on every platform for the same class of reason — on Windows, opening an idle Bluetooth serial port can block for minutes.

## Exit status

Status | Meaning
0 | success
1 | the command failed; the reason is printed to standard error
2 | the command was not recognised, or its arguments were wrong
Machine-readable output ( download , | get ) goes to standard output; progress and diagnostics go to
standard error, so | kb2040ctl download > config.json | is safe on every platform.

# Commands

## ports

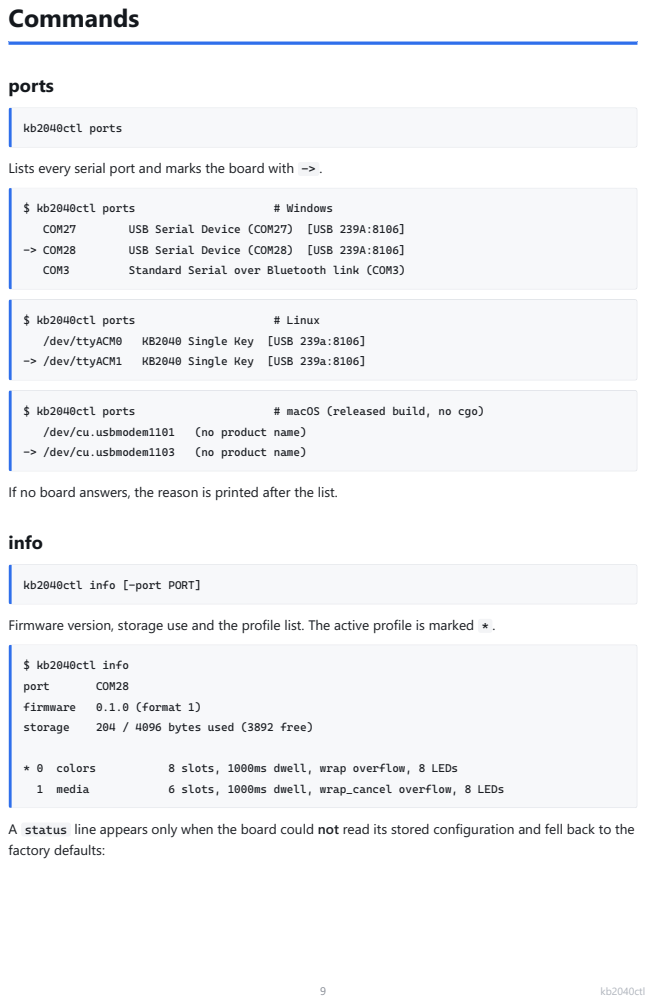
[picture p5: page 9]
kb2040ctl ports; Lists every serial port and marks the board with; $ kb2040ctl ports; # Windows; COM27; USB Serial Device (COM27) [USB 239A:8106]; -> COM28; USB Serial Device (COM28) [USB 239A:8106]; COM3; Standard Serial over Bluetooth link (COM3); # Linux; /dev/ttyACM0; KB2040 Single Key [USB 239a:8106]; -> /dev/ttyACM1; # macOS (released build, no cgo); /dev/cu.usbmodem1101; (no product name); -> /dev/cu.usbmodem1103; info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

If no board answers, the reason is printed after the list.

kb2040ctl info [-port PORT]

status | meaning
blank | nothing has ever been written to NVM
corrupt: … | something was there but failed to decode; the reason follows
no-nvm | the board has no non-volatile memory; configuration is RAM-only
Uploading any configuration clears it.

## download

kb2040ctl download [-port PORT] [-p N] [-o FILE]

Saves the board's configuration as JSON. Writes to standard output unless | -o | is given.
Flag | Meaning
-p N | download only profile N rather than the whole device
-o FILE | write to a file instead of standard output

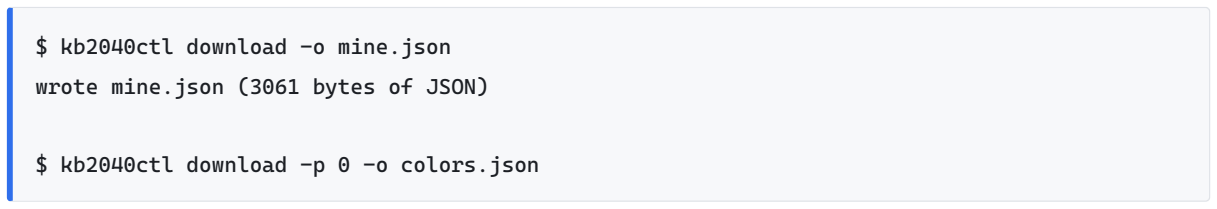
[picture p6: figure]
$ kb2040ctl download -o mine.json; wrote mine.json (3061 bytes of JSON)

$ kb2040ctl download -p 0 -o colors.json

A single-profile file is the right input for upload -p N .

## upload

kb2040ctl upload [-port PORT] [-p N] FILE

Sends a configuration to the board.

Flag | Meaning
-p N | replace only profile N, leaving the others untouched

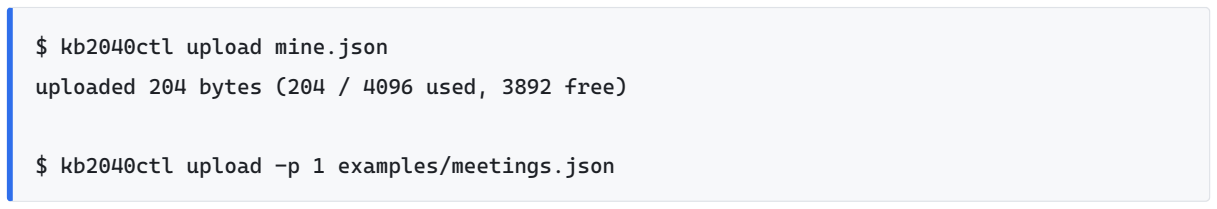
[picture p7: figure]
$ kb2040ctl upload mine.json

uploaded 204 bytes (204 / 4096 used, 3892 free)

$ kb2040ctl upload -p 1 examples/meetings.json

The file is validated and the byte budget checked before anything is sent, and the board checks both again before committing. A configuration that does not fit is refused at both ends and the board is left exactly as it was.
Uploads are atomic. The transfer is buffered and checked in order — character count, decode, byte count, transport checksum, then configuration decode — and only a configuration that passes every check is stored.

## get

kb2040ctl get [-port PORT] PATH

Prints one value from the board's configuration as JSON. Paths are dot-separated; a numeric segment indexes a list.

$ kb2040ctl get profiles.0.dwell_ms
1000
$ kb2040ctl get profiles.0.slots.3.color "#00FF00"
$ kb2040ctl get profiles.0.tap.steps.0 {"key":"PRINT_SCREEN"}

## set

kb2040ctl set [-port PORT] PATH VALUE

Changes one value and uploads the result.

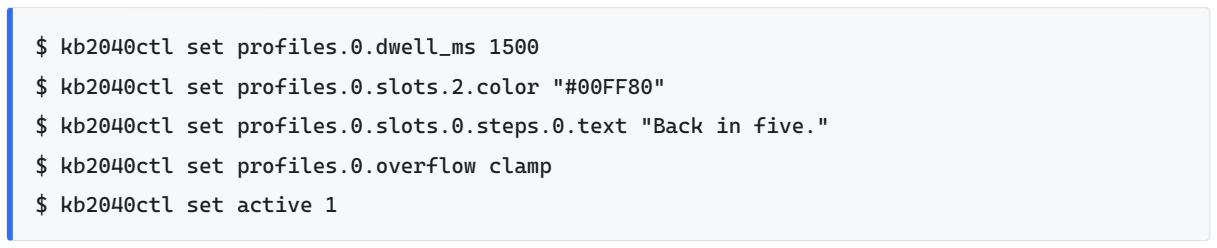
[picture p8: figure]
$ kb2040ctl set profiles.0.dwell_ms 1500; $ kb2040ctl set profiles.0.slots.2.color "#00FF80"; $ kb2040ctl set profiles.0.overflow clamp; $ kb2040ctl set active 1

$ kb2040ctl set profiles.0.slots.0.steps.0.text "Back in five."

set downloads the configuration, applies the edit, validates it and uploads the whole thing. The board has no field-level write on purpose: the configuration is only ever stored as a complete, checksummed unit, so a half-applied configuration cannot exist.
The type already stored at the path decides how the argument is read. A name of | 2024 | stays the string
"2024" ; | dwell_ms 1500 | becomes the number 1500; | quick | where a number belongs is rejected. Lists
and objects are given as JSON:

$ kb2040ctl set profiles.0.tap.steps '[{"key":"F5"},{"delay_ms":50}]'

In PowerShell, single quotes work the same way; | cmd.exe | needs double quotes with the inner ones
escaped, so a JSON value is easier from PowerShell.

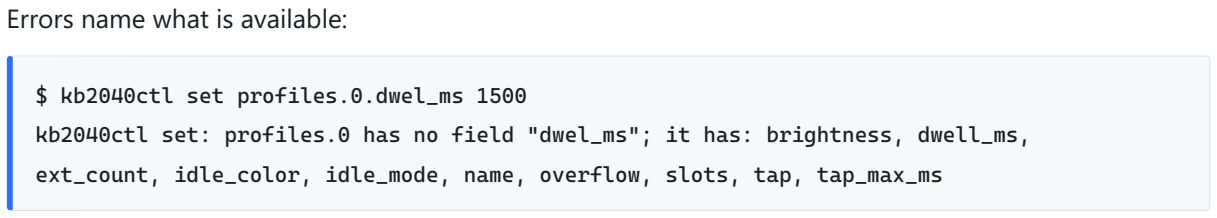
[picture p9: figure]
Errors name what is available:; $ kb2040ctl set profiles.0.dwel_ms 1500

kb2040ctl set: profiles.0 has no field "dwel_ms"; it has: brightness, dwell_ms, ext_count, idle_color, idle_mode, name, overflow, slots, tap, tap_max_ms

## profile

Lists the profiles, or switches the active one. Switching is persistent.

## test

kb2040ctl test [-port PORT] PROFILE BINDING

Fires a binding immediately, without touching the key. Binding 0 is the tap; 1 upwards are the colour

This sends real keystrokes to whatever window has focus. A text binding will type into your terminal if that is where the cursor is. Use it to separate a wiring or timing problem from a configuration problem, with the cursor somewhere harmless.

## watch

kb2040ctl watch [-port PORT]

Streams key and colour-slot events live. Ctrl-C stops it.

$ kb2040ctl watch
Watching. Tap and hold the key; press Ctrl-C to stop. press
slot 0 FF0000
slot 1 FF6000
slot 2 FFC000
release
fire 3

Event | Meaning
press | key went down
slot N RRGGBB | the hold advanced to slot N, showing that colour
cancel | the hold reached the dark | wrap_cancel | slot
release | key came up
fire N | binding N ran
error … | a binding raised; the configuration port stays alive
This is the tool for tuning timing. Overshooting slots means | dwell_ms | is too short; a deliberate tap
landing on slot 0 means | tap_max_ms | is too short.

## validate

kb2040ctl validate [-p] FILE

Checks a configuration file and reports the byte budget. No board required — useful in an editor loop or in CI.

Flag | Meaning
-p | the file holds a single profile rather than a whole device configuration

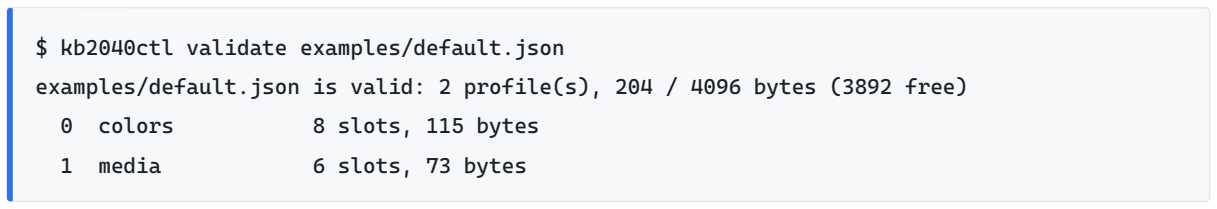
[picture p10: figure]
$ kb2040ctl validate examples/default.json; 0 colors; 8 slots, 115 bytes; 1 media; 6 slots, 73 bytes

examples/default.json is valid: 2 profile(s), 204 / 4096 bytes (3892 free)

## defaults

kb2040ctl defaults [-port PORT] [-y]

Restores the factory configuration, replacing every profile. Asks for confirmation unless | -y | is given.
Download a copy first if the current configuration is worth keeping.

## keys

kb2040ctl keys [media]

Lists every key name a configuration may use, or with media , every Consumer Control name. Needs no board.

## version

kb2040ctl version

Prints the tool's own version.

# Configuration file format

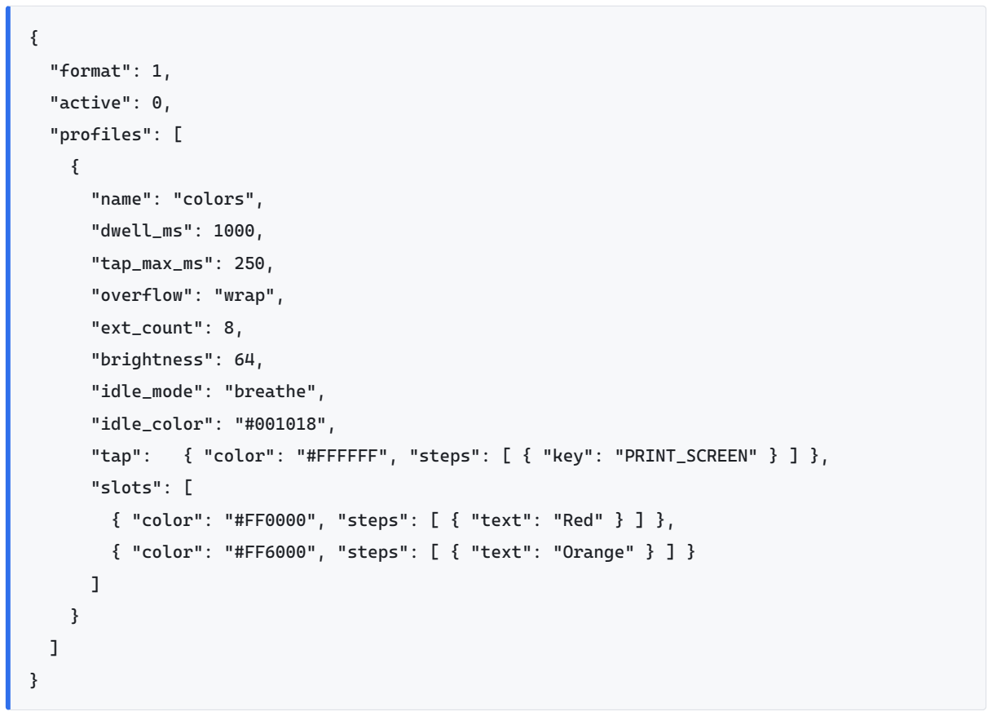
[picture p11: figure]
"format": 1,; "active": 0,; "profiles": [; "name": "colors",; "dwell_ms": 1000,; "tap_max_ms": 250,; "overflow": "wrap",; "ext_count": 8,; "brightness": 64,; "idle_mode": "breathe",; "idle_color": "#001018",; "slots": [

"tap": { "color": "#FFFFFF", "steps": [ { "key": "PRINT_SCREEN" } ] },

{ "color": "#FF0000", "steps": [ { "text": "Red" } ] },
{ "color": "#FF6000", "steps": [ { "text": "Orange" } ] }

Files are plain UTF-8 JSON and move between platforms unchanged; line endings do not matter.

## Profile fields

Field | Range | Meaning
name | ≤ 16 bytes | shown by | info | and | profile list
dwell_ms | 100–10000 | how long each colour is displayed
tap_max_ms | 20–2000 | release under this counts as a tap
overflow | wrap , | wrap_cancel , | clamp | behaviour past the last colour
ext_count | 0–64 | external WS2812 chain length; 0 disables it
brightness | 0–255 | applies to every LED
idle_mode | off , | solid , | breathe , | rainbow | animation when the key is idle
idle_color | #RRGGBB | used by | solid | and | breathe
tap | binding | fired by a quick tap
slots | 1–16 bindings | the colour slots, in cycle order
Up to 8 profiles, subject to the byte budget.

## Binding and step fields

A binding is | { "color": "#RRGGBB", "steps": [ … ] } . A step sets exactly one of:
Field | | | Type | | Notes
key | name | with optional | mods
text | string | 1–255 bytes
consumer | name | Consumer Control usage
delay_ms | 0–10000 | wait
mods | accompanies | key | only and accepts | CTRL , | SHIFT , | ALT , | GUI , and the | R -prefixed right-hand
forms. | WIN | and | CMD | are accepted as aliases for | GUI , which is the same HID modifier bit on every
platform — the host decides what it means. Run | kb2040ctl keys | for key names and | kb2040ctl keys
media | for media names. An unrecognised name is rejected with a list of valid ones. A numeric form
such as | 0x68 | is also accepted for a raw HID usage ID.
Up to 64 steps per binding.
Keystrokes are sent as HID usage codes, so what a key produces depends on the host's keyboard layout. Text steps are typed via a US layout; on a host set to another layout, punctuation in a text step may not come out as written.

## The byte budget

The whole configuration lives in the RP2040's 4096-byte non-volatile region. That is what lets it persist
while the | CIRCUITPY | drive stays writable from your computer.
There is no fixed per-profile limit — spend the space as you like. As a rule of thumb, a slot with a key or media action costs about 8 bytes, and a slot that types a sentence costs about 6 bytes plus the length of the text. The two-profile factory configuration uses 204 bytes, leaving room for roughly thirty more profiles of that size.
validate | and | upload | both report usage, and an oversized configuration is refused before anything is
sent.

# Troubleshooting

## Any platform

no kb2040-single-key found . Either the board is not running this firmware, or another program already holds the port — a serial monitor, the Mu editor, the Arduino IDE. Close it, or pass -port explicitly.
Only one serial port appears. | boot.py | has not run. It takes effect only on a hard reset: unplug and
replug, or press the reset button. A soft reload is not enough.
info | shows a | status | that is not | ok . The board could not read its stored configuration and is
running the factory defaults. | blank | is normal on a board that has never been configured. Uploading
any configuration clears it.
The LEDs work but the key does nothing. The switch is not reaching | D4 / GND . Run | kb2040ctl watch
— no | press | line means the firmware never sees the key.
The key fires the wrong slot. Run | kb2040ctl watch | and hold the key. If the slots advance faster than
you can react, raise | dwell_ms ; if a quick tap registers as slot 0, raise | tap_max_ms .
Nothing at all on the LEDs at startup. The firmware is not running. Check the REPL on the console serial port for a traceback — a missing library is the usual cause.

## Windows

SmartScreen blocks the binary. It is not code-signed. More info → Run anyway, or Unblock-File .
\kb2040ctl.exe .
A command hangs for a long time. Older builds probed every serial port, including Bluetooth ones, which can block for minutes. Current builds probe only USB ports; if you are on an older binary, pass -port explicitly.

## macOS

"cannot be opened because the developer cannot be verified". Gatekeeper quarantine. Clear it with
xattr -d com.apple.quarantine ./kb2040ctl .
permission denied | when running it. Missing the executable bit: | chmod +x ./kb2040ctl .
A command hangs. Check you are not pointing | -port | at a | /dev/tty.* | name. Use the | /dev/cu.*
twin; the | tty. | variant waits for carrier detect that a USB CDC port never asserts. Autodetect already
avoids them.
ports shows no vendor or product IDs. Expected on the released macOS binaries, which are built without cgo and so cannot read USB descriptors. Identification is unaffected. Build from source natively if you want the IDs.

## Linux

permission denied | opening | /dev/ttyACM1 . Your user is not in the port's group. Add yourself to
dialout | (Debian, Ubuntu, Raspberry Pi OS) or | uucp | (Arch, some Fedora), then log out and back in:

sudo usermod -aG dialout "$USER"

Confirm with | groups , and check the port's owner with | ls -l /dev/ttyACM* .
The first command after plugging in fails, then it works. ModemManager probes new | /dev/ttyACM*
devices for a few seconds, assuming they might be a cellular modem, and holds the port while it does. Install the udev rule in Installing → Linux to exempt the board, or if you have no modems at all:

sudo systemctl mask ModemManager

No | CIRCUITPY | volume when flashing. Many minimal or headless installs do not automount removable
media. Find it with | lsblk -o NAME,LABEL,MOUNTPOINT , mount it, and pass the path:

scripts/flash.sh --drive /mnt/CIRCUITPY

kb2040ctl: command not found | after moving it to | /usr/local/bin . That directory is on the default
PATH | on most distributions but not all; check with | echo $PATH .

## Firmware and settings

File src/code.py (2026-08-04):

"""kb2040-single-key: one key, colour-tap bindings, WS2812 feedback, serial configuration.

This is the only module that touches hardware. Everything with logic in it lives under
``singlekey/`` and imports nothing from CircuitPython, so it is covered by host tests.

Wiring (see README.md):

    key switch            board.D4  -> GND      (internal pull-up, active low)
    onboard NeoPixel      board.NEOPIXEL (GP17)
    external WS2812 data  board.D10
"""

import time

import board
import digitalio
import microcontroller
import neopixel
import supervisor
import usb_cdc

from adafruit_hid.consumer_control import ConsumerControl
from adafruit_hid.keyboard import Keyboard
from adafruit_hid.keyboard_layout_us import KeyboardLayoutUS
import usb_hid

from singlekey import blob, colortap, protocol
from singlekey.actions import ActionRunner
from singlekey.keystate import Debouncer
from singlekey.leds import LedEngine
from singlekey.nvmstore import NvmStore
from singlekey.ticks import ticks_diff

KEY_PIN = board.D4
EXT_PIN = board.D10
MAX_EXT = 64

DEBOUNCE_MS = 20
FRAME_MS = 20  # LED refresh interval; 50 Hz is smooth and leaves the loop plenty of time
FIRE_FLASH_MS = 120


class Device:
    """Owns the hardware and the live configuration, and is what the protocol acts on."""

    def __init__(self):
        self.store = NvmStore(getattr(microcontroller, "nvm", None))
        self.config_obj, self._status = self.store.load()

        self.keyboard = Keyboard(usb_hid.devices)
        self.runner = ActionRunner(
            keyboard=self.keyboard,
            layout=KeyboardLayoutUS(self.keyboard),
            consumer=ConsumerControl(usb_hid.devices),
            sleep=time.sleep,
        )

        self.onboard = neopixel.NeoPixel(board.NEOPIXEL, 1, auto_write=False, brightness=1.0)
        self.ext = None
        self._ext_count = 0

        profile = self.config_obj.active_profile()
        self.leds = LedEngine(profile, max_ext=MAX_EXT)
        self.gesture = colortap.ColorTap(profile)
        self._apply_profile()

    # ------------------------------------------------------------ protocol interface

    def nvm_size(self):
        return self.store.size

    def status(self):
        return self._status

    def config(self):
        return self.config_obj

    def read_blob(self):
        # NvmStore returns what is actually in NVM; on a board with no NVM there is nothing
        # to read back, so fall back to re-encoding what is live.
        stored = self.store.read_blob()
        return stored if stored is not None else blob.encode(self.config_obj)

    def commit(self, data):
        written = self.store.save(data)
        self.config_obj = blob.decode(data)
        self._status = self.store.status
        self._apply_profile()
        return written

    def set_active(self, n):
        self.config_obj.active = n
        written = self.store.save_config(self.config_obj)
        self._apply_profile()
        return written

    def restore_defaults(self):
        self.config_obj = blob.default_config()
        written = self.store.save_config(self.config_obj)
        self._status = self.store.status
        self._apply_profile()
        return written

    def fire(self, profile_index, binding_index):
        binding = self.config_obj.profiles[profile_index].binding(binding_index)
        steps = self.runner.run(binding)
        self.leds.flash(binding.color, supervisor.ticks_ms(), FIRE_FLASH_MS)
        return steps

    # ------------------------------------------------------------------- hardware

    def _apply_profile(self):
        profile = self.config_obj.active_profile()
        self.leds.set_profile(profile)
        self.gesture.set_profile(profile)
        self._set_ext_count(self.leds.ext_count)

    def _set_ext_count(self, count):
        """(Re)build the external chain object. NeoPixel's length is fixed at construction,
        so a config change that alters the chain length has to replace the object -- and
        driving 64 pixels when 8 are connected would waste ~2ms of every frame."""
        if count == self._ext_count:
            return
        if self.ext is not None:
            self.ext.deinit()
            self.ext = None
        if count:
            self.ext = neopixel.NeoPixel(EXT_PIN, count, auto_write=False, brightness=1.0)
        self._ext_count = count

    def show_leds(self, now):
        self.leds.render(now)
        self.push_pixels()

    def push_pixels(self):
        """Copy the engine's buffers to the hardware. Separate from show_leds so the
        startup sweep can drive the pixels without going through the idle renderer."""
        buf = self.leds.onboard
        self.onboard[0] = (buf[0], buf[1], buf[2])
        self.onboard.show()

        if self.ext is not None:
            ebuf = self.leds.ext
            for i in range(self._ext_count):
                base = 3 * i
                self.ext[i] = (ebuf[base], ebuf[base + 1], ebuf[base + 2])
            self.ext.show()

    def startup_sweep(self):
        """Run the rainbow self-test across the onboard pixel and the external chain.

        Blocking on purpose: it happens once, before the key or the config port matter,
        and it is the only sign of life the board gives if something is wrong early.
        """
        start = supervisor.ticks_ms()
        while True:
            elapsed = ticks_diff(supervisor.ticks_ms(), start)
            if not self.leds.boot_frame(elapsed):
                break
            self.push_pixels()
            time.sleep(FRAME_MS / 1000)


class KeyReader:
    """Debounced reader for a single active-low switch.

    Only the pin read lives here; the debounce itself is in ``singlekey.keystate`` so it
    is host-testable.
    """

    def __init__(self, pin):
        self.io = digitalio.DigitalInOut(pin)
        self.io.direction = digitalio.Direction.INPUT
        self.io.pull = digitalio.Pull.UP
        self._debounce = Debouncer(not self.io.value, DEBOUNCE_MS)

    @property
    def pressed(self):
        return self._debounce.pressed

    def poll(self, now):
        """Return True on a press edge, False on a release edge, None if nothing changed."""
        return self._debounce.update(not self.io.value, now)
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

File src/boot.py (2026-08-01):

"""USB configuration. Runs once at power-up, before code.py.

Changes here only take effect after a hard reset (replug or the reset button), not after a
soft reload.

Two things are set up:

* a **second CDC serial port** alongside the REPL console. The configuration protocol lives
  on the data port so that talking to the board never fights with the console, and so a
  serial monitor left open on the REPL does not eat config traffic.
* the HID devices this keyboard actually needs -- keyboard and consumer control. The mouse
  is left off; every device in the descriptor costs enumeration time and report bandwidth
  for no benefit here.

The CIRCUITPY drive is deliberately *not* remounted read-only. Configuration lives in
microcontroller.nvm precisely so the drive stays writable from the host.
"""

import supervisor
import usb_cdc
import usb_hid

usb_cdc.enable(console=True, data=True)

usb_hid.enable((usb_hid.Device.KEYBOARD, usb_hid.Device.CONSUMER_CONTROL))

# Names the port in the host's device list. VID/PID are left alone so the board still
# enumerates as an Adafruit device and needs no new drivers.
supervisor.set_usb_identification(manufacturer="jeremy.ninja", product="KB2040 Single Key")

# Recorded in boot_out.txt. Without this there is no way to tell "boot.py ran and worked"
# from "boot.py never ran" -- both leave boot_out.txt holding just the CircuitPython banner,
# and the difference matters because the config port only exists if this file ran.
print("kb2040-single-key: usb_cdc console+data enabled, HID = keyboard + consumer control")

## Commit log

2026-08-01 Add binary config format spec and Go encoder/decoder
    Defines the on-device configuration format (docs/format.md) that both the
    CircuitPython firmware and the Go CLI implement: a variable-length little-endian
    blob with a profile offset table and a CRC-16/CCITT-FALSE trailer, sized to fit
    the RP2040's 4KB microcontroller.nvm.
    Adds the Go side of the contract: internal/blob (types, validation with
    actionable errors, encode/decode, HID key and consumer name tables, host-facing
    JSON) and internal/wire (Ascii85 in 80-char lines, the serial wire encoding).
    Golden fixtures in tests/fixtures pin the format so the CircuitPython
    implementation cannot drift from this one.
2026-08-01 Add CircuitPython firmware: colour-tap gesture, LEDs, NVM config, serial protocol
    Implements the device side of docs/format.md. src/singlekey holds all the logic
    and imports nothing from CircuitPython, so every part of it runs under host
    pytest; boot.py and code.py are the only modules that touch hardware.
    - colortap: the gesture itself - tap window, one colour slot per dwell, and the
    three overflow modes (wrap, wrap_cancel, clamp). Elapsed time goes through
    ticks_diff so a hold spanning the 2**29 ms wraparound resolves correctly.
    - blob/nvmstore: decoder plus a defaults encoder, with recovery from blank,
    corrupt or foreign NVM so no stored byte pattern can stop the board booting.
    - a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
    [boot.py, code.py]
2026-08-01 Add kb2040ctl, the cross-platform Go configuration CLI
    Thirteen commands over the serial protocol: ports, info, download, upload,
    get, set, profile, test, watch, validate, defaults, keys, version.
    internal/device holds the protocol client. The board exposes two CDC ports with
    identical USB IDs and only one answers, so the port is found by protocol
    handshake rather than by VID/PID; ports are still tried vendor-first so unrelated
    serial devices are less likely to be probed at all. The transport is an
    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
2026-08-01 Add CI, release workflow, flash script, README and examples
    CI runs the firmware host tests, the CLI tests, gofmt and vet, and a six-target
    cross-compile matrix. It also fails if the committed golden fixtures differ from
    what the encoder generates, so the two implementations cannot drift silently.
    The release workflow builds static binaries for windows/linux/darwin on
    amd64/arm64 for a v* tag and publishes them with checksums.
    Both workflows are test-and-publish only: this repository has no AWS stack, so
    there is no OIDC job and no credential beyond GITHUB_TOKEN.
    scripts/flash.ps1 locates the CIRCUITPY volume, installs the CircuitPython
    libraries with circup and mirrors src/, removing the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
2026-08-01 Mark plan milestones complete; hardware bring-up blocked on the board
2026-08-01 Run a rainbow sweep across every LED at startup
    On every start the board sweeps the colour wheel across the onboard NeoPixel and
    the whole external chain, then fades into the profile's idle animation.
    This is a self-test, not decoration. It runs before the key or the config port
    matter, so it is the only feedback available if the wiring is wrong: every
    configured pixel lighting with a smooth spread proves the data line, the chain
    length and the power all work. For that reason it ignores the profile's
    idle_mode and enforces a brightness floor, so a profile configured with the LEDs
    off or dark cannot make the one available diagnostic invisible.
    _rainbow and the sweep now share a wheel painte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
    [code.py]
2026-08-01 Record hardware bring-up finding: board is running Arduino firmware
2026-08-01 Bring up on hardware: fix three device-only bugs, default to colour-name typing
    Factory profile 0 is now "colors": a tap sends Print Screen, and each colour
    slot types the name of the colour it is showing (Red, Orange, Yellow, Green,
    Cyan, Blue, Violet, Magenta) - one slot per LED in the default chain, in the
    order the startup sweep paints them, so the gesture teaches itself. Profile 1
    keeps the media controls and the delay step that keeps the golden vector
    covering all four step types.
    Three bugs that only real hardware could surface:
    - nvmstore read NVM with bytes(self.nvm). microcontroller.nvm is an
    nvm.ByteArray - sized and sliceable but not iterable - so the firmware died
    with Typ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
    [boot.py]
2026-08-01 Add a CLI manual and correct the README against real bring-up
    docs/manual.md is a 13-page reference for kb2040ctl: the colour-tap model,
    board discovery, exit status, every command with flags and worked examples, the
    configuration schema, the byte budget and troubleshooting.
    scripts/build-manual.py renders it to docs/kb2040ctl-manual.pdf with pandoc and
    WeasyPrint, so the styling is versioned alongside the text and the PDF can be
    regenerated rather than hand-maintained.
    Two tests assert the manual documents exactly the CLI's registered commands, in
    both directions, mirroring the guard already on the README.
    README corrections, all things bring-up proved wrong:
    - Bootloader entry now cover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
2026-08-01 Make the manual, flashing and macOS port selection work on all three platforms
    The manual documented Windows and little else, and scripts/flash.ps1 left macOS
    and Linux users with no way to get firmware onto the board at all.
    - docs/manual.md gains an Installing chapter per platform: release asset per
    target, Windows SmartScreen, macOS Gatekeeper quarantine, and Linux serial
    permissions with both the dialout group and a udev rule. Port naming is
    documented per platform, ports shows example output on each, and
    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
2026-08-02 Probe for the board in two passes so autodetection is not slow
    Autodetection worked but paid the full 3-second command timeout ruling out the
    REPL console port, which sits next to the configuration port and never answers.
    Measured on hardware: 3.7s autodetected versus 0.44s with -port.
    It now probes every candidate with a 500ms timeout first, which is ample for a
    board that replies in milliseconds, and only then makes a second pass at the
    full timeout. The patient pass stays because silence is not proof of the wrong
    port: a binding containing a delay step can occupy the firmware for up to ten
    seconds, during which the real board is merely busy.
    Same board after the change: 1.1s.
    The probe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
2026-08-02 Add BigSwitchCase STL/SCAD, release diagram, and hardware build guide.
    Ship the Kailh Big Switch base mesh with matching OpenSCAD source, document the side-tab screwdriver release openings, and expand the README with Adafruit BOM links (KB2040, NeoPixel Jewel, Big Switc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
    [BigSwitchCase.scad, BigSwitchCase.stl]
2026-08-02 Hero the colour-tap demo video in the README.
    Add videos/demo.mp4 and a poster frame so the project opens with a clear
    picture of hold-for-colour and release-to-type.
2026-08-02 Embed a playable colour-tap demo video in the README.
    Use a GitHub user-attachments CDN URL so the README renders a native
    video player; repo-hosted mp4 files do not play inline.
2026-08-02 Embed a playable colour-tap demo video in the README.
    Point the hero at a GitHub user-attachments CDN URL so the README renders
    a native video player instead of a static poster or GIF.
2026-08-03 Fix flash.ps1 clobbering itself when singlekey/ already exists on the board
    Copy-Item -Recurse onto an existing destination directory copies the source
    *into* it, so re-flashing a board that already had singlekey/ produced
    singlekey/singlekey and failed with "Access to the path is denied". The
    preceding Remove-Item is not sufficient: the FAT driver on a CircuitPython
    volume does not always retire the directory entry by the time it returns.
    Copy the modules in one at a time instead, which also stops the repo's
    src/singlekey/__pycache__ host .pyc files being copied onto a 7 MB drive.
2026-08-04 Fix the key dying on boot when ticks_ms starts past the half-period
    KeyReader seeded its debounce timestamp with 0, but supervisor.ticks_ms()
    counts from an arbitrary epoch -- 0 is not "long ago", just another point on
    a 2**29 circle. When a boot started in the upper half of that range,
    ticks_diff(now, 0) came out negative, so every edge failed the debounce test.
    Worse, _last_change is only assigned on an accepted edge, so it stayed 0 and
    the key never recovered: dead until the counter wrapped, up to ~74 hours.
    Observed on hardware booting at tick 536806681, where ticks_diff(now, 0) was
    -64231 and 100 consecutive polls all returned None while the pin itself was
    reading the switch correctly.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
    [code.py]
